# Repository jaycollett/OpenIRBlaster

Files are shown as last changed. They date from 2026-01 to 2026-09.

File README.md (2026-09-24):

# OpenIRBlaster

An open-source IR receiver and transmitter for Home Assistant. Custom PCB, 3D-printed case, ESPHome firmware, about $22 to $25 in parts.

[][releases]
[](LICENSE)
[][hacs]

📖 **[Read the full story and build guide on my blog](https://www.jaycollett.com/2026/02/openirblaster-finally-truly-simple-ir-control-for-home-assistant/)**

## The integration is deprecated. The hardware is not.

Home Assistant 2026.4 added a built-in `infrared` entity platform, and [HAIR](https://github.com/DAB-LABS/HAIR) builds a full IR code manager on top of it: a live signal sniffer, protocol decoding, climate state matrices, and import from SmartIR, Flipper Zero, LIRC and Girr. It does everything this integration does and a great deal more, and it is in the HACS default store.

So this integration is winding down. It still works, it is not going to break tomorrow, and nothing is being deleted in this release. It will not gain new features.

The hardware is unaffected and is where this project continues. OpenIRBlaster is a board, a case, a bill of materials and a firmware image, none of which HAIR provides.

**If you are already using this integration:** move your codes across before you delete its storage file. From version 1.3.2, removing the integration leaves that file in place. Version 1.3.1 and earlier deleted it along with the integration, so on those versions update or move your codes first. Your stored codes hold the carrier frequency measured when each was learned, and the new infrared platform does not report one, so anything re-learned later comes back at the 38 kHz default. See [Moving your codes to HAIR](#moving-your-codes-to-hair). Nothing is deleted and your setup keeps working while you check the result.

**If you are new here:** build the hardware, flash it, and use it with HAIR.

## What it is

A dedicated ESP8266 board built around IR, rather than a general-purpose dev board with an LED soldered on.

Transistor-driven IR LEDs (eight of them, 39 ohm limiting resistors, IRLML6344 MOSFET) give strong output and 360 degree coverage, so it works across a room rather than only when pointed at the target. A TSOP38238 receiver handles learning. The ESPHome firmware ships with `dashboard_import`, so the ESPHome dashboard can adopt the device with one click.

Everything needed to build one is in [`hardware/`](hardware/): schematic and board layout, the bill of materials, STLs for the case, the firmware source and a prebuilt binary.

## Requirements

- Home Assistant 2024.12 or newer for this integration.
- For HAIR, check its own requirements. Native IR capture and plucking need Home Assistant 2026.6 or newer, because that is the release where the infrared receiver API landed. 2026.9 or newer is the safer floor.
- An OpenIRBlaster board, or other ESPHome hardware with an IR receiver and transmitter.

See the [Hardware Overview](docs/hardware-overview.md) for the build.

## Moving your codes to HAIR

### Do this before you delete anything

Every code you learned here carries the carrier frequency measured when it was captured. Home Assistant's infrared platform does not report a carrier, so a code you learn again afterwards comes back at the 38 kHz default.

Most remotes are 38 kHz and would not notice. A device running at 36 or 40 kHz would, and for those the difference is the code working or not working. That measured value exists in one place only, this integration's storage file, and re-learning cannot bring it back.

Both routes below preserve it. Take one of them before you delete `.storage/openirblaster_<entry_id>`.

From version 1.3.2, removing the integration in Home Assistant keeps that file, so your codes are still on disk afterwards and the command-line export below can convert them. Version 1.3.1 and earlier deleted the file when you deleted the integration entry, so if you are on one of those versions, update or export first.

If you remove a blaster and add it again, Home Assistant gives it a new entry ID and a new, empty storage file. The old file stays next to it with your codes in it. Once those codes are safely in HAIR you can delete the old file by hand.

### Pluck from HAIR (recommended)

HAIR pulls the codes out of this integration directly. No files to move, no remote to point at anything, and no infrared is broadcast while it happens.

1. Install HAIR from HACS and set it up.
2. Open HAIR, go to the **Plucker** tab, and add OpenIRBlaster as a blaster.
3. Pluck your codes by name.

This works because the integration implements HAIR's pluckable contract. See [Plucking codes into HAIR](docs/pluckable.md) for what that means and how it works.

### Export to a file

If you would rather move files yourself, or HAIR is not installed yet.

From the UI, while this integration is still installed:

1. Go to **Developer Tools** -> **Actions**.
2. Choose **OpenIRBlaster: Export codes to HAIR**.
3. Pick your device, and optionally choose how to split the codes into files.
4. Run it.

Files land in `hair/wigs/` in your Home Assistant config directory, which is where HAIR looks.

HAIR treats one file as one remote, so the **Split into** option matters if your library covers several devices. Splitting by tag or by the first word of each code name gives you one remote per device instead of one long list. You can re-split inside HAIR later either way.

From the command line, which also works after you have removed the integration (on 1.3.2 or later, where removal keeps the file):

```bash
python3 tools/openirblaster_to_wig.py ~/.homeassistant/.storage/openirblaster_<entry_id>
```

The file name has no extension, and there is one per blaster, so `ls ~/.homeassistant/.storage/openirblaster_*` shows you what to pass.

Run `--help` for output directory and grouping options. It needs nothing but Python 3.12 or newer and never writes to the file it reads. `custom_components/openirblaster/wig_export.py` is the whole implementation in one file with no imports from anything else, so you can copy that single file somewhere and run it if the repository is not handy.

### After moving

Check the codes work in HAIR before removing anything here. If a code did not convert, or carried tags or notes, the file export writes `openirblaster-export-receipt.txt` next to the wigs listing what was dropped and why. Tags and notes have no equivalent in HAIR's format, so they are reported rather than silently merged.

Keep your `.storage` file until you are satisfied. Removing the integration does not touch it, so when you no longer need it, delete it by hand.

## Installation

### HACS

1. Open HACS.
2. Click **Integrations**.
3. Click **+ Explore & Download Repositories**.
4. Search for "OpenIRBlaster".
5. Click **Download**.
6. Restart Home Assistant.
7. Go to **Settings** → **Devices & Services** → **Add Integration** and search for "OpenIRBlaster".

### Manual

1. Download the [latest release](https://github.com/jaycollett/OpenIRBlaster/releases).
2. Copy `custom_components/openirblaster` into your Home Assistant `custom_components` directory.
3. Restart Home Assistant.
4. Add the integration from **Settings** → **Devices & Services**.

## Using the integration

### Learn a code

1. Find the **Code Name** text field in your device's entity list.
2. Enter a name, for example "TV Power".
3. Press **Learn IR Code**.
4. Within 30 seconds, point your remote at the receiver and press the button.
5. A new button entity appears with that name.

### Manage codes

Rename by calling `openirblaster.rename_code` with the code's `id` and a `new_name`. The button updates immediately and its entity ID does not change, so automations keep working.

Delete from **Settings** → **Devices & Services** → **OpenIRBlaster** → **Configure** → **Manage IR Codes**. Deletion is always select-then-confirm.

Codes can also be saved, sent, renamed and deleted from scripts. See the [Home Assistant Integration](docs/home-assistant-integration.md) docs for the full service reference.

### Use in automations

```yaml
automation:
  - alias: "Turn off TV at bedtime"
    trigger:
      - platform: time
        at: "23:00:00"
    action:
      - service: button.press
        target:
          entity_id: button.openirblaster_tv_power
```

## Compatibility

The integration finds devices by ESPHome project name, looking for firmware that declares `project.name: "jaycollett.openirblaster"`. If you are building your own hardware, include that identifier in your ESPHome YAML or fork the integration.

### Third-party devices

Community members have run OpenIRBlaster on hardware it was not designed for. See [`docs/third-party-devices/`](docs/third-party-devices/):

- [Tuya IR Blasters](docs/third-party-devices/tuya-ir-blasters.md), covering S06, S18 and similar Tuya-branded repeaters

[PRs adding a guide are welcome](docs/third-party-devices/README.md#contributing-a-new-device-guide).

## Documentation

Full documentation lives in [`docs/`](docs/README.md):

- [Hardware Overview](docs/hardware-overview.md), schematic, components and build guide
- [Firmware & ESPHome](docs/firmware-and-esphome.md), flashing and configuration
- [Home Assistant Integration](docs/home-assistant-integration.md), setup, entities, services and automation examples
- [Plucking codes into HAIR](docs/pluckable.md), how HAIR pulls codes out of this integration
- [Storage Format & Manual Editing](docs/storage-format.md), on-disk schema and hand-edit procedure
- [Troubleshooting](docs/troubleshooting.md), common issues and solutions

## Development

- [`TESTING.md`](TESTING.md), testing instructions
- [`hardware/`](hardware/), hardware design files

### ESPHome firmware

The firmware configuration is at [`hardware/firmware/factory_flash.yaml`](hardware/firmware/factory_flash.yaml). To contribute changes, modify the YAML, test on your own device, and keep event names, service calls and entity IDs compatible with the integration. See the [Firmware & ESPHome](docs/firmware-and-esphome.md) docs.

### Integration

```bash
git clone https://github.com/jaycollett/OpenIRBlaster.git
cd OpenIRBlaster
python3 -m venv venv
source venv/bin/activate
pip install -r requirements_dev.txt

pytest
```

## Support

- [Report bugs or request features](https://github.com/jaycollett/OpenIRBlaster/issues)
- [Project documentation](docs/README.md)

## License

MIT. See [LICENSE](LICENSE).

## Acknowledgments

Built for the Home Assistant community. Thanks to the ESPHome project for the firmware platform, to the Home Assistant community, and to [DAB-LABS](https://github.com/DAB-LABS/HAIR) for building the IR code manager this project no longer needs to.

### Transparency note: AI-assisted development

The Home Assistant integration for this project was developed with assistance from [Claude Code](https://claude.ai/code), Anthropic's AI coding assistant. AI-assisted development is a powerful tool when used responsibly by engineers who understand the code being generated, validate its correctness, and take ownership of the final result. I reviewed, tested, and take full responsibility for all code in this repository. AI assistance accelerated development but doesn't replace engineering judgment, thorough testing, or understanding of the underlying systems.

---

[releases-shield]: https://img.shields.io/github/v/release/jaycollett/OpenIRBlaster
[releases]: https://github.com/jaycollett/OpenIRBlaster/releases
[license-shield]: https://img.shields.io/github/license/jaycollett/OpenIRBlaster.svg
[hacs]: https://github.com/hacs/integration
[hacsbadge]: https://img.shields.io/badge/HACS-Default-orange.svg

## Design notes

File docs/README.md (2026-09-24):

# OpenIRBlaster Documentation

OpenIRBlaster is an open-source infrared transceiver designed for Home Assistant integration via ESPHome. These pages cover building, configuring, and troubleshooting the device.

For the project's elevator pitch and install instructions, see the [root README](../README.md). For a narrative build log, see the [project blog post](https://www.jaycollett.com/2026/02/openirblaster-finally-truly-simple-ir-control-for-home-assistant/).

## Hardware Specs

| Parameter | Value |
|---|---|
| Microcontroller | ESP-12F (ESP8266) |
| IR Frequency | 38kHz (configurable) |
| IR LEDs | 8x IR333-A 940nm |
| Power Input | 5V DC via USB-C |
| Power Draw | ~500mA peak (1A supply recommended) |
| Connectivity | Wi-Fi 802.11 b/g/n |

## Pages

### Getting Started
- [Hardware Overview](hardware-overview.md) - Schematic walkthrough, component selection, and design rationale

### Configuration
- [Firmware & ESPHome](firmware-and-esphome.md) - Flashing instructions, YAML configuration, and integration compatibility requirements
- [Home Assistant Integration](home-assistant-integration.md) - Device setup, entities, services, and automation examples

### Reference
- [Storage Format & Manual Editing](storage-format.md) - On-disk schema for `.storage/openirblaster_*` and the safe procedure for hand-editing it
- [Troubleshooting](troubleshooting.md) - Common issues and solutions

### Third-Party Hardware
- [Tuya IR Blasters](third-party-devices/tuya-ir-blasters.md) - S06, S18, and similar Tuya-branded IR repeaters
- [Adding a new device guide](third-party-devices/README.md#contributing-a-new-device-guide)

## Project Resources

| Resource | Link |
|---|---|
| Source Code | [GitHub Repository](https://github.com/jaycollett/OpenIRBlaster) |
| Hardware Files | [Eagle CAD Files](https://github.com/jaycollett/OpenIRBlaster/tree/master/hardware) |
| Blog Post | [Project Introduction](https://www.jaycollett.com/2026/02/openirblaster-finally-truly-simple-ir-control-for-home-assistant/) |
| ESPHome | [ESPHome Documentation](https://esphome.io) |

## Contributing

Contributions are welcome. Please submit issues and pull requests through the [GitHub repository](https://github.com/jaycollett/OpenIRBlaster).

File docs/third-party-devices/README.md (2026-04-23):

# Third-Party Device Support

OpenIRBlaster was designed around a [purpose-built PCB](../../hardware/), but the firmware and Home Assistant integration are not strictly tied to that hardware. Any ESPHome-flashable IR device that exposes the same events and services can work with the integration.

This directory collects community-contributed guides for running OpenIRBlaster on hardware that wasn't designed for it. These are provided as-is by the contributors listed in each guide; they may not have been tested by the maintainer.

## Available Guides

| Device Family | Notes | Contributor |
|---|---|---|
| [Tuya IR Blasters](tuya-ir-blasters.md) | Various Tuya-branded IR repeaters (S06, S18, etc.) flashed via tuya-cloudcutter | [@Stoatwblr](https://github.com/Stoatwblr) |

## What You'll Need to Make It Work

The Home Assistant integration identifies compatible devices by ESPHome project name. Any ESPHome YAML used with this integration must declare:

```yaml
esphome:
  project:
    name: "jaycollett.openirblaster"
    version: "1.0.0"
```

It also needs to expose the events and services the integration listens for. Use [`hardware/firmware/factory_flash.yaml`](../../hardware/firmware/factory_flash.yaml) as the reference implementation - the event names, service signatures, and entity IDs there define the contract.

## Contributing a New Device Guide

If you've successfully run OpenIRBlaster on hardware not listed here, PRs are welcome. A useful guide includes:

- Device name(s) and where to buy them
- The chip / board variant(s) you tested on
- Pinout(s) for IR TX, IR RX, status LED, and any buttons
- The flashing method (tuya-cloudcutter, esptool, etc.)
- A working ESPHome YAML snippet (or full file) showing the device-specific bits
- Anything that surprised you (case opening difficulty, GPIO probing, etc.)

Open a PR adding a new file to this directory and a row to the table above.

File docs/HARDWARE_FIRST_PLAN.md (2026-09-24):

# OpenIRBlaster hardware-first plan

Status: proposal, awaiting approval. No source files changed.
Written 2026-09-19 against v1.2.3 (commit 6e8f4ad, branch master, clean).

The premise: HAIR (https://github.com/DAB-LABS/HAIR, MIT) already did the infrared-domain migration this project was about to start, at a scope OpenIRBlaster was never going to match. HAIR owns no hardware and no firmware. OpenIRBlaster does. This plan moves the repo's centre of gravity to the hardware, makes OpenIRBlaster a first-class device under HAIR, and gets existing users' code libraries across without re-learning anything.

Sources. Repo claims carry a path or `file:line`. HAIR claims were read from the clone at `scratchpad/HAIR` and are cited `HAIR:<path>:<line>`; they agree with the independent analysis at `scratchpad/hair-analysis.md`, and where I measured something that document states more strongly than I can, I say so. ESPHome claims were read from `raw.githubusercontent.com/esphome/esphome/dev`. `infrared_protocols` claims were executed against version 10.1.0 under Python 3.14.7.

---

## Priority zero: the chip, and what each answer costs

### The hardware is ESP8266, ESP-12F module, ESPHome board `esp12e`

Settled from the repo, four independent confirmations:

- `hardware/BOM.csv:12`: `MCU,ESP8266,MCU,ESP-12F,ESP-12F`
- `hardware/firmware/factory_flash.yaml:21-22`: `esp8266:` then `board: esp12e`
- `hardware/firmware/factory_flash.yaml:195`: "Hardware schematic shows GPIO4/GPIO5 are swapped in the ESP-12F footprint"
- `custom_components/openirblaster/__init__.py:394`: `model="ESP8266 IR Blaster"`

There is no ESP32 variant anywhere in the repo. Every shipped unit is this board.

### Can ir_rf_proxy run on it

I cannot settle this from the repo and ESPHome source alone, and I will not guess. Here is exactly what the evidence does and does not establish.

Verified, and it is the encouraging half. Nothing gates ESP8266 at config time. I grepped `esphome/components/ir_rf_proxy/infrared.py`, `esphome/components/ir_rf_proxy/__init__.py` and `esphome/components/infrared/__init__.py` for `esp8266`, `esp32`, `only_on`, `not_on` and `PLATFORM`, and the only hit is `IS_PLATFORM_COMPONENT = True` (`infrared/__init__.py:22`). The C++ carries feature guards, `#ifdef USE_IR_RF` and `#ifdef USE_RADIO_FREQUENCY` (`ir_rf_proxy/ir_rf_proxy.h:9,13,19,45`), and no platform guards. The component is a thin layer over `remote_base` (`AUTO_LOAD = ["remote_base"]`, `infrared/__init__.py:20`), attaching by id through `remote_base.attach_receiver` (`ir_rf_proxy/infrared.py:89-90`). `remote_base` works on ESP8266 today, which is how the current firmware functions at all. So there is no structural reason it should fail.

Not verified, and it cannot be from source. Whether it compiles for `esp12e`, whether the image fits in flash, and whether it runs without exhausting RAM once the native API also holds an infrared receive subscription. The existing firmware is already managing RAM deliberately: `buffer_size: 6kb` and a comment at `factory_flash.yaml:204` reading "ESP8266-safe: avoid dump: all (can contribute to RAM pressure)". That is not a board with headroom.

The discouraging half, and it deserves weight. Nobody upstream has an ESP8266 config.

- All five HAIR reference configs are ESP32 family: `esp32dev`, `esp32-c3-devkitm-1`, `esp32doit-devkit-v1`, `esp32-s3-devkitc-1`, `seeed_xiao_esp32c3` (`HAIR:esphome/README.md`, availability table).
- The official `esphome/infrared-proxies` repo contains exactly one device directory, `xiao-ir-mate`, ESP32-C3. I listed the repo through the GitHub API.
- ESPHome's own `ir_rf_proxy` docs publish no chip support matrix, which the parallel analysis also found (`hair-analysis.md:94`).

Zero ESP8266 prior art across all three. That is not proof of failure. It does mean OpenIRBlaster would be first, with nobody to copy and nobody to ask.

### What would settle it

One command, which the parallel agent is running:

```
esphome compile factory_flash.yaml    # with the infrared: block from section 2, ESPHome 2026.5.0+
```

Three outcomes worth distinguishing, because they are not the same problem:

1. Compiles and fits, runs stable. Proceed with the whole plan.
2. Compiles but overruns flash or RAM. Recoverable by trimming the firmware: drop `dump:`, drop the legacy `send_ir_raw` and `replay_last_ir` services and the `openirblaster_learned` event once HAIR is the path, shrink `buffer_size`. That reclaims real space, since those exist only to serve the integration this plan winds down.
3. Does not compile for `esp8266`. Not recoverable in firmware.

### Consequences of each answer

If it works, existing units follow with a reflash and no board revision. Everything below proceeds as written.

If it does not, there is no fallback. HAIR talks only to the infrared domain ("HAIR does not talk to hardware directly. It sits on HA's native infrared platform for both capture and send", and `dependencies: ["http", "infrared"]` in `HAIR:custom_components/hair/manifest.json`). A device that cannot register an `infrared` entity is invisible to HAIR, whatever else its firmware exposes. The legacy event and service path does not help, because HAIR will not read it.

That leaves two branches, and both are Jay's call rather than mine:

- Revise the board to ESP32-C3. A schematic change, a new BOM, a new layout, a fab run and new firmware. Weeks and real money. It also gets the chip everyone else in this ecosystem is on, which has value beyond this one problem.
- Accept that Rev A stays on the legacy integration and only a future revision works with HAIR. Cheap now, and it means the wind-down in section 4 cannot go past a thin shim, because the shim is the only way Rev A users keep working at all.

Note what does not change under either branch. The export tool in section 3 reads a JSON file and writes a JSON file. It never touches the device. Existing users get their code libraries out regardless of how the compile goes, and that is why it is the first thing to build.

---

## 1. Hardware asset inventory

Eight files, 1.2 MB, all under `hardware/`.

| Asset | Path | Size | Notes |
|---|---|---|---|
| Schematic | `hardware/Eagle Files/Open_IR_Blaster.sch` | 607 KB | Autodesk Eagle format |
| Board layout | `hardware/Eagle Files/Open_IR_Blaster.brd` | 111 KB | Autodesk Eagle format |
| Schematic image | `hardware/Eagle Files/open_ir_blaster_sch.png` | 100 KB | Rendered, viewable without Eagle |
| Bill of materials | `hardware/BOM.csv` | 693 B | 14 line items |
| Enclosure top | `hardware/3DPrinterFiles/Top.stl` | 206 KB | STL only |
| Enclosure bottom | `hardware/3DPrinterFiles/Bottom.stl` | 347 KB | STL only |
| Factory firmware source | `hardware/firmware/factory_flash.yaml` | 9.3 KB | ESPHome YAML, project version `0.5.0` at line 14 |
| Factory firmware binary | `hardware/firmware/factory_flash.bin` | 420 KB | Prebuilt, flashable via ESPHome Web |

### What does not exist

Checked rather than assumed, because the brief asked for several of these by name:

- No gerbers. I searched the repo for `*.gbr`, `*.gbl`, `*.gtl`, `*.drl` and `*.zip` and found none. The Eagle `.brd` can generate them, but no fab-ready output is committed, so nobody can order a board from this repo without installing Eagle and running a CAM job.
- No drill files, pick-and-place, fab notes or assembly drawing.
- No KiCad project. Eagle only, which matters because Eagle is end-of-life as a standalone product and KiCad is where the open-hardware audience now is.
- No STEP, 3MF or source CAD for the case. Two STLs, so it cannot be modified without remodelling it.
- No hardware-scoped licence. The repo `LICENSE` covers the software; board and case normally carry a separate CERN-OHL or CC-BY-SA.

For a repo whose argument is about to become "we own the hardware", the missing fab package is the most visible gap.

### Circuit summary

| Function | Part | GPIO | Config |
|---|---|---|---|
| IR receive | TSOP38238, 38 kHz (`BOM.csv:14`) | GPIO5 | `INPUT_PULLUP`, inverted (`factory_flash.yaml:197-202`) |
| IR transmit | IR333-A 940 nm (`BOM.csv:13`) via IRLML6344 MOSFET (`BOM.csv:10`) | GPIO14 | `carrier_duty_percent: 50%` (`factory_flash.yaml:283-285`) |
| LED current limiting | 8 x 39 ohm R1210 (`BOM.csv:6`) | | Eight in parallel, a hard-driven emitter |
| Power | Adafruit 4907 USB port (`BOM.csv:8`), AZ1117IH-3.3 (`BOM.csv:9`) | | |

Receiver tuning today: `buffer_size: 6kb`, `tolerance: 50%`, `filter: 50us`, `idle: 25ms`, `dump: raw` (`factory_flash.yaml:204-213`).

The firmware ships `dashboard_import` (`factory_flash.yaml:17-19`) pointing at `github://jaycollett/OpenIRBlaster/hardware/firmware/factory_flash.yaml@master`, so the device is adoptable straight from the ESPHome dashboard. That is a real distribution asset and it should survive every change below.

---

## 2. ESPHome ir_rf_proxy configuration

Conditional on priority zero. Do not ship this until the compile passes.

### 2.1 How the component works, and why the legacy path survives

`ir_rf_proxy` is a platform of ESPHome's `infrared:` component. Its schema requires exactly one of `remote_transmitter_id` or `remote_receiver_id`, each a `cv.use_id` reference to an existing component (`ir_rf_proxy/infrared.py:24-38`). It sits on top of `remote_receiver` and `remote_transmitter` rather than replacing them, so a device doing both needs two entries against the same hardware.

That is what makes the transition cheap and reversible. Adding an `infrared:` block is purely additive. The existing `send_ir_raw` service (`factory_flash.yaml:30-43`), the `esphome.openirblaster_learned` event (`:64-77`, `:261-266`) and the `replay_last_ir` recovery service keep working against the same `ir_rx` and `ir_tx` ids. One firmware serves both the legacy integration and HAIR, so users migrate on their own schedule instead of on a flag day, and a bad ESPHome release does not strand anybody. Keep both blocks.

Two config rules, read from source:

- A transmitter whose `carrier_duty_percent` is 0 or 100 is rejected at final validation (`ir_rf_proxy/infrared.py:63-69`). OpenIRBlaster already sets 50% (`factory_flash.yaml:285`), so this passes unchanged.
- `receiver_frequency` is rejected on a transmitter entry (`ir_rf_proxy/infrared.py:44-48`), and on a receiver entry the source calls it "metadata only, no hardware effect" (`:92-94`). It never reaches Home Assistant, which is why captured signals arrive with `modulation=None`.

Require ESPHome 2026.5.0 or newer, not the bare 2026.1.0 minimum. The component broke HA entity setup as late as 2026-02-24, gained `receiver_frequency` in March and an `on_control` trigger in May. It is also marked EXPERIMENTAL in its own source, verbatim: "This component is EXPERIMENTAL. The API (both Python configuration and C++ interfaces) may change at any time without following the normal breaking changes policy." (`infrared/__init__.py:4-8`).

### 2.2 Proposed config

Written to HAIR's contribution convention. Their header template (`HAIR:esphome/_template/header-template.yaml`) is mandatory, and their README states PRs without a fully filled header are not merged.

```yaml
# ============================================================================
# HAIR ESPHome Config
# ----------------------------------------------------------------------------
# Device:            OpenIRBlaster (ESP-12F / ESP8266)
# Hardware revision: Rev A
# Variant:           full
# Contributor:       @jaycollett
# Source:            https://github.com/jaycollett/OpenIRBlaster
# License:           Apache 2.0
# Tested against:
#   HAIR:            <fill after testing>
#   HA Core:         <fill after testing>
#   ESPHome:         <fill after testing, 2026.5.0 minimum>
# Last verified:     <YYYY-MM-DD>
# Purpose:           RX+TX
# Hardware purchase: DIY, see hardware/ in the repo
# GPIO map:
#   GPIO5            IR RX (TSOP38238, inverted, pull-up)
#   GPIO14           IR TX (IR333-A via IRLML6344)
# Notes:
#   - ESP8266. No ESP8266 ir_rf_proxy reference config exists upstream.
#     Compile-tested on esp12e, see the repo for results.
#   - dump: is omitted deliberately. The proxy attaches to remote_receiver
#     directly and does not need it; on ESP8266 the decoders cost RAM.
#   - The legacy send_ir_raw service and openirblaster_learned event are
#     retained so the pre-HAIR path still works on the same firmware.
# ============================================================================

infrared:
  - platform: ir_rf_proxy
    name: "${friendly_name} TX"
    id: ir_proxy_tx
    remote_transmitter_id: ir_tx

  - platform: ir_rf_proxy
    name: "${friendly_name} RX"
    id: ir_proxy_rx
    receiver_frequency: 38kHz
    remote_receiver_id: ir_rx
```

Three changes to `remote_receiver` (`factory_flash.yaml:197-213`) worth making at the same time:

Drop `dump: raw`. It only drives log output. The proxy gets timings through `remote_base.attach_receiver` regardless, so removing it costs nothing and buys RAM on the chip that section 0 says has none to spare. If outcome 2 from priority zero happens, this is the first thing to cut anyway.

Raise `idle` from 25 ms. HAIR's references use 100 ms (`HAIR:esphome/generic-esp32-c3/generic-esp32-c3-minimal.yaml:87`). At 25 ms a long air-conditioner frame can be truncated mid-signal, which presents as a code that captures but does not replay. Climate matrices are something HAIR is good at, so this matters more under HAIR than it did before.

Consider `tolerance` 25% instead of 50%. HAIR uses 25%; 50% is loose enough to merge symbols on some protocols. Change this only if capture testing says so, since the current value is recorded in the repo as a stable result from prior testing.

---

## 3. Code library export tool

The priority deliverable for existing users. Nothing else here matters to them if the codes they learned one press at a time do not survive.

### 3.1 Answering the carrier_hz question first

The brief asked whether `.wig.json` can hold `carrier_hz` and what is lost if not. Good news: it holds it, and nothing is lost.

A wig has no `carrier_hz` field, no `pulses` field and no `timings` field. The payload is Pronto hex only (`HAIR:custom_components/hair/wig_format.py:1-14`). That looks like a problem until you look at what Pronto is. The second word of a Pronto preamble is the carrier, encoded as a divisor of a fixed reference frequency (`infrared_protocols/commands/pronto.py:13`, `:59-78`). Encoding `{pulses, carrier_hz}` into Pronto writes the carrier into the code, and any reader gets it back.

I measured the round trip rather than taking it on faith:

| carrier_hz in | preamble word | decoded back | error |
|---|---|---|---|
| 36000 | `0073` | 36045 Hz | +45 Hz (0.13%) |
| 38000 | `006d` | 38029 Hz | +29 Hz (0.08%) |
| 40000 | `0068` | 39857 Hz | -143 Hz (0.36%) |
| 56000 | `004a` | 56015 Hz | +15 Hz (0.03%) |

The analysis document says Pronto "preserves the carrier exactly" (`hair-analysis.md:366`). It preserves it to the quantization of the frequency word, which is within 0.36% across the whole IR band. A TSOP receiver has a passband thousands of Hz wide, so this is irrelevant in practice, and calling it exact is close enough for a user-facing sentence. It is not literally exact, so a converter should not assert byte-equality in a test.

The wider point is worth stating plainly, because it inverts the concern behind the question. Jay's existing codes carry real captured carrier values. New captures through `ir_rf_proxy` will not, because ESPHome delivers `modulation=None`. Exporting to `.wig.json` now, from the current library, is the one moment where those measured carriers are still in hand. Every code exported keeps its 36 kHz or 40 kHz forever. Every code re-learned through the new path after deleting the old library comes back at the 38 kHz default. That is an argument for doing the export before anything else, and for telling users not to delete their `.storage` file until they have run it.

### 3.2 Source schema, OpenIRBlaster

Storage lives at `<HA config>/.storage/openirblaster_<entry_id>`, one file per device, in Home Assistant's standard `Store` envelope with the payload under `data`. The envelope is built at `custom_components/openirblaster/storage.py:84-92`; the store is constructed at `storage.py:69-74` with `STORAGE_VERSION` and `STORAGE_MINOR_VERSION` from `const.py:35-36`, currently 1 and 1.

One code object, written at `storage.py:143-152`:

| Field | Type | Source | Meaning |
|---|---|---|---|
| `id` | string | `storage.py:144`, generated at `:211-227` | Lowercase slug from the original name, collision-suffixed `_2`, `_3`. Stable across renames |
| `name` | string | `storage.py:145` | Display name, mutable |
| `carrier_hz` | int | `storage.py:146` | Validated `> 0` at `learning.py:644-650`, typically 38000 |
| `pulses` | list[int] | `storage.py:147` | Signed microseconds, positive mark and negative space. Max 2000 (`const.py:22`) |
| `created_at` | ISO string | `storage.py:148` | UTC |
| `updated_at` | ISO string | `storage.py:149` | UTC |
| `tags` | list[string] | `storage.py:150` | May be empty |
| `notes` | string | `storage.py:151` | May be empty |

The device block also carries `config_entry_id`, `name`, `device_id` and an optional `last_learned` summary (`storage.py:259-263`). The whole format is already documented for users at `docs/storage-format.md`.

The sign and unit convention matches HAIR's encoder input contract exactly, which is why this conversion is arithmetic rather than interpretation.

### 3.3 Target schema, `.wig.json`

From `hair-analysis.md` section 8, cross-checked against the clone. A wig is one JSON object describing one remote. A minimal valid file:

```json
{
    "format": "hair-wig/3",
    "name": "Living Room TV",
    "signals": [
        {"alias": "Power", "pronto": "0000 006d 0004 0000 0156 00ac 0015 0017"}
    ]
}
```

Required on parse (`wig_format.py:537-711`): `format` matching `^hair-wig/(\d+)$`, a non-empty `name`, and a non-empty `signals` list whose entries each have a non-empty `alias` and a `pronto` that passes `validate_pronto`. Stamp `hair-wig/3`, which is what the current exporter writes for a flat wig (`wig_format.py:1037-1039`). Known per-signal keys are `alias`, `pronto`, `send_count`, `send_spacing_ms`, `ditto_count`, `bypass_protocol` (`wig_format.py:318-321`). For a converter, only `alias` and `pronto` matter; leave the rest out and let the parser apply defaults.

Unknown keys are tolerated and preserved through parse and re-serialize, at top level and per signal, which is the documented growth mechanism. A converter can safely stamp private keys.

Two schema slots worth using. `converted_from` and `converted_from_sha256` (`wig_format.py:120-121`) are the provenance pair: name the source tool and hash the `.storage` file it came from. `kind` comes from a fixed 27-word vocabulary (`wig_format.py:172-200`) and HAIR's own exporter refuses to guess one; the converter should leave it unset and let HAIR ask. File cap is 16 MB (`wig_format.py:102`), suffix `.wig.json`.

Import needs no HAIR code at all. Drop the file into `/config/hair/wigs/` over SSH or Samba and HAIR picks it up, which means the converter never has to integrate with anything.

### 3.4 The conversion

Use `ProntoCommand` from `infrared_protocols`, which ships with Home Assistant as a requirement of the `infrared` domain:

```python
from infrared_protocols.commands.pronto import ProntoCommand

pronto = ProntoCommand.from_raw_timings(code["pulses"], modulation=code["carrier_hz"]).to_pronto_hex()
# -> "0000 006d 0004 0000 0156 00ac 0015 0017 0015 0041 0015 05cb"
```

HAIR's own `raw_to_pronto(timings, frequency=...)` (`HAIR:custom_components/hair/ir_command.py:357`) does the same job and is 50 lines of dependency-free arithmetic that could be vendored. Prefer the `infrared_protocols` route for a standalone script, since it is already installed next to Home Assistant.

Four facts I verified by execution rather than reading:

Output case is lowercase and that is fine. `to_pronto_hex` builds from `bytes.hex()` (`pronto.py:81-83`), so words come out `006d` not `006D`. HAIR's validator accepts both (`pronto_validator.py:67`) and its canonical form lowercases anyway (`wig_format.py:1410-1420`).

The header is always `0000`, the modulated learned format, which is one of the two headers HAIR accepts (`0000` and `0100`). Compatible without special handling.

Odd-length pulse arrays fail. Pronto encodes burst pairs, so an array ending on a mark with no trailing space raises `ValueError: pronto timing data does not match the preamble burst pair counts`. I reproduced it with a 7-element array. Whether OpenIRBlaster ever writes odd-length arrays depends on how the firmware's `on_raw` handler terminates, which I did not trace. The converter should append a trailing gap when the length is odd and record it in the receipt rather than doing it silently.

Timings quantize, by up to 45µs on a 560µs interval, about 8 percent. Well inside NEC-family decode tolerance, which is 40 percent in the same library (`nec.py:15`). Worth spot-checking converted codes against real hardware before telling users the export is safe, particularly for long air-conditioner frames.

### 3.5 Field mapping

| OpenIRBlaster | wig | Handling |
|---|---|---|
| `data.device.name`, or the entry title | `name` | Required. Fall back to "OpenIRBlaster" plus the entry id |
| `code.name` | `signals[].alias` | Required, stripped, preserved verbatim |
| `code.pulses` + `code.carrier_hz` | `signals[].pronto` | Both encode into the one string. Carrier included |
| source file SHA-256 | `converted_from_sha256` | Provenance |
| (tool name) | `converted_from` | Provenance |
| `code.notes` | no per-signal target | Receipt file |
| `code.tags` | no target | Receipt file |
| `code.id` | no target | Dropped. Aliases are display names; HA entity ids are not portable |
| `code.created_at`, `code.updated_at` | no target | Dropped |
| (user choice) | `kind`, `brand`, `model` | Left unset. HAIR asks |

`notes` and `tags` are the only real loss, and it is small. They are per-code in OpenIRBlaster with no per-signal equivalent in a wig, which carries a single top-level `notes` string. Do not concatenate them into it; a merged blob attributed to no particular code is worse than nothing. Write a sidecar receipt listing code id, name, tags and notes, so anything worth keeping can be pasted back by hand. HAIR's own exporter does the same kind of skip accounting and surfaces it beside the export (`HAIR:custom_components/hair/wig_export.py:64-71`).

### 3.6 Grouping and delivery

One wig is one remote. An OpenIRBlaster library is a flat list per device, so a 40-code library covering three devices becomes one wig of 40 unrelated buttons unless the converter splits it. Offer `--group-by` with `file` (default, one wig per storage file, always correct if untidy), `tag` (one per distinct tag, remainder wig for untagged, best outcome for anyone who used tags) and `prefix` (split on the first name token, which suits the common "TV Power" / "TV Volume Up" habit). Users can re-split inside HAIR either way.

Ship it as `tools/openirblaster_to_wig.py` in this repo. No HAIR dependency, no HA import, reads a `.storage` file and writes wigs plus a receipt. Take a path in, write to a directory, never touch the source. Point the docs at the existing warning in `docs/storage-format.md` about HA caching `.storage` in memory.

Second, and not blocking: contribute a format probe and adapter to HAIR so users can drag the raw `.storage` JSON into its drop zone. HAIR dispatches on a prioritized probe list (`HAIR:custom_components/hair/wig_adapters.py:196-203`) already carrying SmartIR, Girr, Flipper and LIRC. An `openirblaster` probe is an easy match: a JSON object with `data.codes` whose entries have `id`, `pulses` and `carrier_hz`. That is the nicer experience and it puts OpenIRBlaster's name in HAIR's supported-formats list, which is free visibility for the hardware. It is also a PR on someone else's schedule, so the script must not wait for it.

---

## 4. Integration wind-down

Options with tradeoffs, not a decision. My recommendation is at the end.

### Option A: thin turnkey shim

Strip the integration to what HAIR does not cover. In practice: drop learning entirely, since HAIR's sniffer is better, and keep a read-only view of the existing library with its send buttons.

A v1.2.3 user upgrades, keeps their buttons, loses the Learn button, gains nothing. New codes go in HAIR, old codes stay in OpenIRBlaster storage, and the library is split permanently. Any HA change to the ESPHome event or service API is still Jay's to fix.

Nobody's dashboard breaks, which is the argument for it. Against: it preserves the exact thing this pivot exists to end, and guarantees every user ends up with two libraries.

This becomes the only viable option if priority zero fails, because a shim is then the only way Rev A hardware works at all.

### Option B: deprecate with a migration path

Ship a deprecation release that adds an `openirblaster.export_to_hair` service and an options-flow button writing the `.wig.json` from section 3 straight into `/config/hair/wigs/`, raises a persistent repair issue explaining the move and linking HAIR, and updates the README and HACS description. Everything else keeps working. After a stated grace period, stop feature work and archive.

A v1.2.3 user upgrades, nothing breaks, they get a notice and a one-click export. They install HAIR, import, and remove the old integration when ready. Nobody is forced and nobody re-learns a code.

Most work of the three, and most of that work is the export, which section 3 says to build regardless. The deprecation release is a thin wrapper over it.

### Option C: freeze

Stop releasing. README points at HAIR. Code stays on master and keeps working until HA breaks it.

A v1.2.3 user notices nothing until something breaks, then finds an unmaintained integration and no migration path. The dependency is on `esphome` event and service APIs, which are stable, so that could be a long time. Zero effort, worst experience, and it wastes the export by not putting it in front of anyone.

### Recommendation

Option B, shipped as **v1.2.4** rather than a 1.3. The version number is doing real work here: 1.3.0 signals a feature release and invites users to expect continued development, while a patch bump reads as what it is, a maintenance release whose entire content is the exit path. It also keeps the door open to a genuine 1.3.0 later if priority zero fails and option A becomes necessary.

Sequence it so the export ships before the deprecation notice, not with it. A repair issue telling users to migrate, pointing at a tool that does not exist yet, is worse than saying nothing.

### What the HACS entry should say

`hacs.json` currently reads `{"name": "OpenIRBlaster", "homeassistant": "2024.12.0"}`. Under option B the description should say in its first line that this is the integration for OpenIRBlaster hardware, that HAIR is the recommended way to use the device going forward, and that this integration exists to carry existing libraries across. It should not read as a competing general-purpose IR integration, because it stops being one.

One release mechanic, recorded in `docs/SESSION_KNOWLEDGE.md`: the Release workflow auto-tags and publishes from `manifest.json` on every master push, and CI fails any master push whose manifest version matches the latest release tag. Docs-only commits cannot be pushed alone; bundle them with a version bump.

### Version floors carried forward from the v2 research

These stop being OpenIRBlaster's problem under this plan, and become facts to state accurately in the docs, because they now describe what HAIR requires of a user rather than what Jay has to build against.

- The infrared receiver API landed in HA 2026.6.0, not 2026.4.0. I verified this by fetching `homeassistant/components/infrared/__init__.py` at every release tag: `async_subscribe_receiver` is absent at 2026.4.0 and 2026.5.0 and present from 2026.6.0. HAIR's `hacs.json` floors at 2026.4.0, which is correct for its emitter-only and bridge paths but not for native capture. Recommend 2026.9.0 in OpenIRBlaster's own docs.
- Python 3.14 is a hard floor for anything importing `infrared_protocols` (`requires-python = ">=3.14"`, verified from PyPI metadata). HA 2026.6+ requires it anyway. This repo's CI runs Python 3.12 (`docs/SESSION_KNOWLEDGE.md`), so the export tool's test job needs 3.14 even though the shipped integration does not.
- `infrared-protocols` went from 1.1.0 to 10.1.0 in five months, ten majors, with two breaks I verified in code: `get_raw_timings()` changed return type, and the code factory moved from a module-level `make_command` to an `Enum.to_command` method. Core owns the pin, so pinning is unavailable. The export tool uses only `ProntoCommand.from_raw_timings` and `to_pronto_hex`, which is the narrowest possible surface, and vendoring the 50 lines of Pronto arithmetic is the escape hatch if that surface moves.

---

## 5. README and positioning

The repo currently presents as a Home Assistant integration that happens to have hardware. Invert that.

Open by saying what the hardware is: an open-source ESP8266 IR blaster for Home Assistant, with schematic, board, BOM, enclosure and prebuilt firmware in the repo, linking the rendered schematic PNG so people can see it without Eagle. Then how to get one, which today means building it and should say so honestly until a fab package exists. Then how to flash it, where `dashboard_import` already gives a one-click path from the ESPHome dashboard.

Then the part that changes. Point at HAIR as the recommended software, link its repo and HACS entry, and link the OpenIRBlaster ESPHome config once contributed. Say plainly that the device registers as a standard Home Assistant infrared emitter and receiver, so it works with anything built on that platform. That one sentence is worth more than a feature list, because it says the hardware is not locked to a single piece of software, which is the whole argument for owning hardware instead of an integration.

Close with a short legacy section: what the integration was, that it still works, that it is deprecated in favour of HAIR, and where the export tool lives.

Two distribution moves beyond this repo. Contribute the config to HAIR, which preserves contributor attribution permanently in the header. Also submit to `esphome/infrared-proxies`, the Home Assistant team's own IR proxy config repo, which currently lists one device. Being the second entry there, and the only ESP8266 one, is real visibility for a small hardware project.

Two hygiene items that make the repo read as hardware rather than software with attachments: add a hardware licence distinct from the software `LICENSE`, and publish the fab package from item 3 below.

---

## 6. Ordered plan

Effort in developer-days. Item 0 gates items 2 and 4 and shapes item 5.

### 0. Compile and run ir_rf_proxy on esp12e, 0.5 day

Already running in parallel. Build `factory_flash.yaml` plus the section 2.2 block for `board: esp12e` against ESPHome 2026.5.0+. Confirm it compiles, fits, flashes, produces two `infrared` entities, captures and sends. Record the result in `docs/SESSION_KNOWLEDGE.md` either way, since it is the kind of finding that is expensive to rediscover.

### 1. Code library export tool, 2 days

`tools/openirblaster_to_wig.py` per section 3. Storage reader, Pronto encoding with the odd-length guard, three grouping modes, receipt file, tests against a real exported library on Python 3.14. Independent of item 0, so start it immediately and in parallel. It is what users need most and it works regardless of how the compile goes.

### 2. ESPHome config and firmware release, 1 day

Depends on item 0. Add the `infrared:` block, drop `dump:`, raise `idle`, decide `tolerance` from capture testing, fill the header's tested-against versions, bump `esphome.project.version` from `0.5.0` (`factory_flash.yaml:14`), rebuild `factory_flash.bin`, update `docs/firmware-and-esphome.md`. Keep the legacy service, event and replay path in place.

### 3. Fab package, 1 day

Generate gerbers and drill files from `Open_IR_Blaster.brd`, commit under `hardware/fab/` with a short README naming stackup and fab-house settings. Add a hardware licence. Consider exporting a KiCad project alongside the Eagle files. This is the single change that most turns the repo into something other people can build, and it is the one item here that nobody else in this ecosystem can do for Jay.

### 4. Contribute configs upstream, 0.5 day

Depends on items 0 and 2. PR to HAIR with a filled header, and to `esphome/infrared-proxies`. Small PRs into other people's repos, so open them early and expect them to land on someone else's schedule.

### 5. Deprecation release v1.2.4, 1.5 days

Option B. Wire the item 1 export into an `openirblaster.export_to_hair` service and an options-flow entry writing into `/config/hair/wigs/`, add the deprecation repair issue and strings, update `hacs.json`. Ship after item 1, never before. If item 0 failed, this becomes option A instead and the scope changes.

### 6. README and positioning, 1 day

Section 5. README, `docs/README.md`, the HACS description, and a `docs/SESSION_KNOWLEDGE.md` entry recording why the project pivoted and what the compile found.

### Totals

| Scope | Items | Days |
|---|---|---|
| Everything | 0 through 6 | 7.5 |
| If item 0 fails, no firmware path | 0, 1, 3, 5 as option A, 6 | 5.5 |
| Minimum that gets users their codes | 0, 1, 6 | 3.5 |

Item 1 is worth doing whatever item 0 returns, and it should start now rather than after. Item 3 is worth doing whatever happens to any of the software, because it is the part of this repo nobody else can replace.

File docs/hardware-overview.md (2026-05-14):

# Hardware Overview

This page covers the hardware components and assembly for the OpenIRBlaster.

## Recommended Components

| Component | Specification | Notes |
|---|---|---|
| Microcontroller | ESP8266 (ESP-12E/ESP-12F) or ESP32 | ESP-12F recommended |
| IR Receiver | TSOP38238 | Connected to GPIO5 |
| IR LED | 950nm IR LED (IR333-A or similar) | Connected to GPIO14 |
| MOSFET | IRLML6344 or similar logic-level | For driving IR LED(s) |
| Power | 5V DC via USB-C | 1A supply recommended |

## Circuit Design

The OpenIRBlaster uses a simple but effective design:

- **IR Receiver**: The TSOP38238 connects directly to GPIO5 with built-in signal conditioning
- **IR Transmitter**: GPIO14 drives an IRLML6344 MOSFET which switches the IR LED array
- **Power**: 5V USB-C input with AZ1117-3.3 voltage regulator for the ESP8266

### Schematic

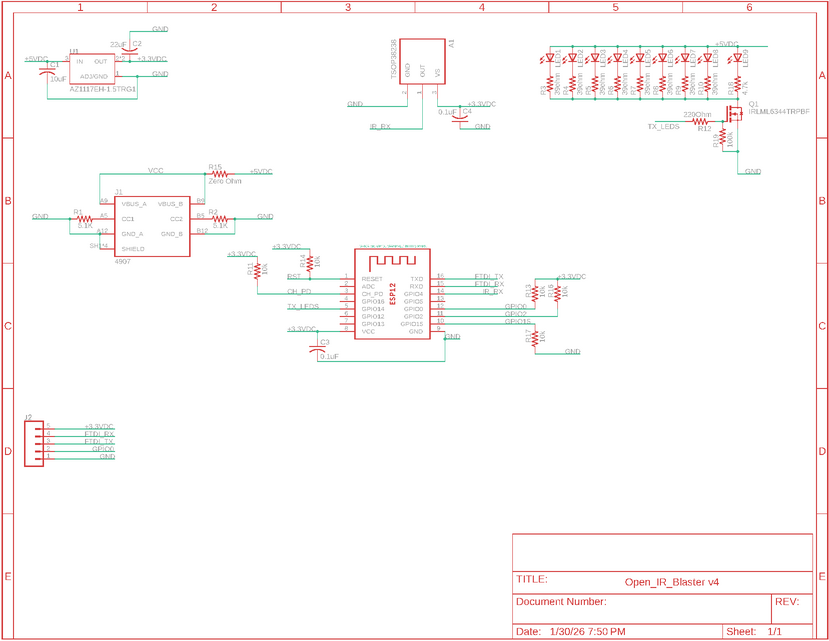
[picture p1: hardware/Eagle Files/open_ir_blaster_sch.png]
OpenIRBlaster Schematic


Full Eagle CAD files are available in the [hardware/Eagle Files](https://github.com/jaycollett/OpenIRBlaster/tree/master/hardware/Eagle%20Files) directory.

## GPIO Assignments

| GPIO | Function |
|---|---|
| GPIO5 | IR Receiver (TSOP38238) |
| GPIO14 | IR Transmitter (via MOSFET) |

## Build Options

### Option 1: Custom PCB

Order PCBs using the Eagle files in the repository. The board is designed for easy hand soldering with 0805 SMD components.

### Option 2: Breadboard Prototype

For testing, you can wire up the components on a breadboard:
1. Connect TSOP38238 to GPIO5
2. Connect IR LED through MOSFET to GPIO14
3. Add appropriate current limiting resistor for IR LED

For a full narrative build walkthrough, see the [project blog post](https://www.jaycollett.com/2026/02/openirblaster-finally-truly-simple-ir-control-for-home-assistant/).

## Design Files

- [Eagle Schematic (.sch)](https://github.com/jaycollett/OpenIRBlaster/tree/master/hardware/Eagle%20Files)
- [Eagle Board (.brd)](https://github.com/jaycollett/OpenIRBlaster/tree/master/hardware/Eagle%20Files)

---

*See [Troubleshooting](troubleshooting.md) for hardware debugging tips.*

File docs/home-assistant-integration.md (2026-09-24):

# Home Assistant Integration

This page covers setting up and using the OpenIRBlaster integration with Home Assistant (integration v1.2.x, HA 2024.12 or later).

## Installation

### HACS (Recommended)

1. Open HACS in your Home Assistant instance
2. Click on **Integrations**
3. Click the **+ Explore & Download Repositories** button
4. Search for "OpenIRBlaster"
5. Click **Download**
6. Restart Home Assistant

### Manual Installation

1. Download the [latest release](https://github.com/jaycollett/OpenIRBlaster/releases)
2. Extract and copy the `custom_components/openirblaster` folder to your Home Assistant `custom_components` directory
3. Restart Home Assistant

## Setup

1. Navigate to **Settings** → **Devices & Services**
2. Click **+ Add Integration**
3. Search for "OpenIRBlaster"
4. Select your ESPHome OpenIRBlaster device from the dropdown
5. Click **Submit**

If you later rename the device in ESPHome, you do not need to remove and re-add the integration - see [Reconfiguring After an ESPHome Rename](#reconfiguring-after-an-esphome-rename).

## Entities and Device Layout

Each blaster is a single device in Home Assistant. Its entities are grouped by section on the device page:

### Controls (main section)
- **{Your Code Names}** - one button per saved code; press to transmit
- **Code Activity** - an event entity that records every capture and save (see [Automating on Code Activity](#automating-on-the-code-activity-event))

### Configuration
- **Code Name** - text field: the name for the next code you learn
- **Learn IR Code** - button: arms learning mode
- **Send Last Learned** - button: replays the most recently captured code (handy for testing before you save)

### Diagnostic
- **Last Learned Code Name** - name of the most recently saved code
- **Last Learned Timestamp** - when the last code was captured
- **Last Learned Pulse Count** - size of the last code (for debugging)

> Upgrading from an older version? The separate "Controls" device is gone; its entities now live on the main device under Configuration. The migration happens automatically at startup.

## Adding a Code

### From the UI (recommended)

1. On the device page, type a name into the **Code Name** field (e.g., "TV Power")
2. Press **Learn IR Code**
3. Within 30 seconds, hold your remote 2-6 inches from the IR receiver and press the button you want to capture
4. A "Code Learned" notification appears, the new code button shows up immediately (no restart or reload needed), and the Code Name field clears itself

Notes on this flow:

- **Timeout:** if no signal arrives within 30 seconds, learning stops, the device's learning mode is switched off, and a "Learning Timed Out" notification appears. Just press **Learn IR Code** again to retry.
- **Duplicate names:** if the name already exists, a "Duplicate Name" notification appears and nothing is saved - pick a different name and learn again.
- **Empty name:** pressing **Learn IR Code** with an empty Code Name shows a "Name Required" notification and does not arm learning.
- **Garbled capture:** if the device receives something it cannot validate, a "Learning Cancelled" notification appears with the reason.

If the integration doesn't pick up the learned code even though ESPHome logs show the IR signal arrived, see [Troubleshooting](troubleshooting.md#ir-receiver-not-learning-codes). As a last resort, codes can be added manually to the storage file - see [Storage Format & Manual Editing](storage-format.md).

### Captured without a name? Use the save form

If a code was captured without a pre-typed name (for example, armed via the `learn_start` service), the capture is held as a *pending* code:

1. Go to **Settings** → **Devices & Services** → **OpenIRBlaster**
2. Click **Configure** on the device
3. The save form opens automatically while a code is pending: enter a **name** (plus optional **tags** and **notes**) and submit

You can also press **Send Last Learned** first to test the pending code before saving it.

### From scripts and automations

`learn_start` arms a learning session. With a response variable, the call waits for the outcome and hands the capture metadata back to your script:

```yaml
action: openirblaster.learn_start
data:
  config_entry_id: "01KESZQ4GF6WSK5XBAA19N96MM"
  timeout: 60
response_variable: capture
```

The response contains `status` (`received`, `timeout`, or `cancelled`) and, on success, `carrier_hz`, `pulse_count`, and `timestamp`. Without `response_variable` the call returns immediately (fire and forget).

After a successful capture, save the pending code with `save_pending`:

```yaml
action: openirblaster.save_pending
data:
  config_entry_id: "01KESZQ4GF6WSK5XBAA19N96MM"
  name: "TV Power"
  tags: "tv, living-room"
  notes: "Samsung TV power toggle"
response_variable: saved   # optional: {code_id, name, carrier_hz, pulse_count}
```

To abort a session, use `learn_cancel`. It refuses to throw away an unsaved capture unless you say so:

```yaml
action: openirblaster.learn_cancel
data:
  config_entry_id: "01KESZQ4GF6WSK5XBAA19N96MM"
  discard_pending: true   # omit (default false) to protect a pending code
```

The `config_entry_id` for all services can be picked from a dropdown in the UI action editor, and switching that action to YAML mode shows the ID itself.

## Renaming a Code

```yaml
action: openirblaster.rename_code
data:
  config_entry_id: "01KESZQ4GF6WSK5XBAA19N96MM"
  id: "tv_power"
  new_name: "Living Room TV Power"
```

The button's display name updates live. The code's `id` and the button's entity ID stay stable, so existing automations keep working.

## Deleting a Code

### From the UI

1. Go to **Settings** → **Devices & Services** → **OpenIRBlaster**
2. Click **Configure** on the device
3. Select **Manage IR Codes**
4. Pick the code from the dropdown
5. Confirm on the deletion screen

The button entity disappears immediately.

### From a service call

```yaml
action: openirblaster.delete_code
data:
  id: "tv_power"
  config_entry_id: "01KESZQ4GF6WSK5XBAA19N96MM"
```

`config_entry_id` is optional with a single blaster, but **required when more than one blaster has a code with the same id** - the service refuses to guess which one you meant.

## Sending Codes

Three ways to transmit:

1. **Code buttons** - press the button entity (or `button.press` it from an automation)
2. **Send Last Learned** - replays the current pending capture, for testing before saving
3. **The `send_code` service** - for scripts, including one-off sends of codes that are not stored:

```yaml
action: openirblaster.send_code
data:
  config_entry_id: "01KESZQ4GF6WSK5XBAA19N96MM"
  id: "tv_power"
response_variable: sent   # optional: {code_id, name, carrier_hz, pulse_count, sent: true}
```

`carrier_hz` and `pulses` can be supplied to override (or send without) a stored code.

## Automating on the Code Activity Event

The **Code Activity** event entity fires two event types:

- `code_learned` - a capture was finalized (attributes: `carrier_hz`, `pulse_count`, `timestamp`, and `rssi` when the firmware provides it)
- `code_saved` - a code was saved to the library (attributes: `code_id`, `name`, `carrier_hz`, `pulse_count`)

```yaml
automation:
  - alias: "Announce captured IR codes"
    trigger:
      - platform: state
        entity_id: event.openirblaster_code_activity
    condition:
      - condition: template
        value_template: "{{ trigger.to_state.attributes.event_type == 'code_learned' }}"
    action:
      - service: notify.mobile_app_phone
        data:
          message: >
            Captured an IR code:
            {{ trigger.to_state.attributes.pulse_count }} pulses at
            {{ trigger.to_state.attributes.carrier_hz }} Hz
```

## Automation Examples

### Turn off TV at bedtime

```yaml
automation:
  - alias: "Turn off TV at bedtime"
    trigger:
      - platform: time
        at: "23:00:00"
    action:
      - service: button.press
        target:
          entity_id: button.openirblaster_tv_power
```

### Voice Control

Use Home Assistant's voice assistants to trigger IR codes:

"Alexa, turn on the TV" -> Triggers IR code via automation

### Conditional Control

```yaml
automation:
  - alias: "Projector for movie time"
    trigger:
      - platform: state
        entity_id: media_player.living_room
        to: "playing"
    condition:
      - condition: state
        entity_id: input_boolean.movie_mode
        state: "on"
    action:
      - service: button.press
        target:
          entity_id: button.openirblaster_projector_power
```

Button entity IDs derive from your device name plus the code name; check the device page for the exact IDs on your install.

## Reconfiguring After an ESPHome Rename

If you rename the device in ESPHome, the integration's stored service binding goes stale. Instead of removing and re-adding:

1. Go to **Settings** → **Devices & Services** → **OpenIRBlaster**
2. Open the entry's menu (three dots) and choose **Reconfigure**
3. Select the (renamed) device and submit

The hardware identity is verified by MAC address: selecting a *different* blaster aborts with "wrong device" (your code library stays bound to its original hardware), and a device whose MAC sensor is unavailable aborts with a distinct message asking you to bring it fully online first.

## Repairs

The integration raises issues under **Settings** → **System** → **Repairs** for conditions you can act on:

| Issue | Meaning | Fix |
|---|---|-----|
| Firmware needs an update | The device sends a corrupted MAC in learned-code events (a bug in old firmware). Learning still works via name matching. | Update the device firmware |
| Could not identify the MAC address | Several ESPHome devices match this entry's name, so the MAC could not be back-filled unambiguously. | Run **Reconfigure** and pick the correct device |
| Cannot send IR codes | The ESPHome send service disappeared after setup (device offline or renamed). | Bring the device online, then reload or reconfigure |

Each issue clears automatically once the condition is resolved.

## Startup Housekeeping

On every startup the integration tidies up after older versions (all idempotent, no action needed):

- migrates entities off the legacy "Controls" device and removes it
- removes orphaned entity registry entries left by removed features (v1.2.1), such as the old per-code delete buttons
- back-fills the device's MAC address into entries created before MAC capture existed
- turns the device's learning mode off if a previous run was interrupted mid-session

## Storage

Learned codes are stored in `.storage/openirblaster_{entry_id}` and include:
- Display name
- Unique ID (slugified)
- Carrier frequency (typically 38kHz)
- Pulse timing array
- Timestamp

Removing the integration keeps this file from version 1.3.2 onwards; 1.3.1 and earlier deleted it with the entry. Delete it by hand once you no longer need the codes. See [When You Remove the Integration](storage-format.md#when-you-remove-the-integration).

For the full schema and a safe procedure for editing the file by hand, see [Storage Format & Manual Editing](storage-format.md).

---

*See [Troubleshooting](troubleshooting.md) for common issues and solutions.*

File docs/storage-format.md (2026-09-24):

# Storage Format & Manual Editing

> **Use case:** the integration normally writes this file for you. Edit it by hand only as a workaround when you can capture an IR signal in ESPHome logs but the integration's learning session isn't picking it up (see issue [#9](https://github.com/jaycollett/OpenIRBlaster/issues/9)).

## File Location

The integration stores all learned codes in Home Assistant's storage area:

```
<HA config>/.storage/openirblaster_<entry_id>
```

The file name has no extension. `<entry_id>` is the config entry ID, and there is one storage file per OpenIRBlaster device added to Home Assistant, so the quickest way to find yours is to list them:

```bash
ls <HA config>/.storage/openirblaster_*
```

Each file carries its own ID and device name under `data.device`, which is how you tell two blasters apart. To look an ID up first instead, `.storage/core.config_entries` lists every config entry with its integration and title, and the **Config entry** dropdown on any OpenIRBlaster action in **Developer Tools -> Actions** fills the ID in for you once you switch that action to YAML mode.

## When You Remove the Integration

From version 1.3.2, deleting an OpenIRBlaster entry in **Settings -> Devices & Services** leaves its storage file where it is. Home Assistant removes the device and its entities, and the file keeps every code, including the carrier frequency measured when each one was learned. The command-line exporter, `tools/openirblaster_to_wig.py`, can still convert it to HAIR's format after the integration is gone.

Version 1.3.1 and earlier deleted the file along with the entry. On one of those versions, export or pluck your codes first, or update before you remove anything.

Adding the same blaster again creates a new config entry with a new ID, and so a new, empty storage file. The old file stays alongside it and the integration does not read it. To bring the codes back into the new entry, copy them across with the [Safe Manual-Edit Procedure](#safe-manual-edit-procedure). Once the codes are somewhere you trust, you can delete the old file by hand.

## On-Disk Format

The file follows Home Assistant's standard storage envelope. Your code data lives inside `data`:

```json
{
  "version": 1,
  "minor_version": 1,
  "key": "openirblaster_01HZABCDEFGHIJK",
  "data": {
    "version": 1,
    "device": {
      "config_entry_id": "01HZABCDEFGHIJK",
      "name": "OpenIRBlaster",
      "device_id": "openirblaster-2ca965",
      "last_learned": {
        "name": "TV Power",
        "timestamp": "2026-04-01T12:34:56+00:00",
        "pulse_count": 8
      }
    },
    "codes": [
      {
        "id": "tv_power",
        "name": "TV Power",
        "carrier_hz": 38000,
        "pulses": [9000, -4500, 560, -560, 560, -1690, 560, -560],
        "created_at": "2026-04-01T12:34:56+00:00",
        "updated_at": "2026-04-01T12:34:56+00:00",
        "tags": [],
        "notes": ""
      }
    ]
  }
}
```

### Schema versioning

The top-level `version` / `minor_version` pair is Home Assistant's storage
envelope versioning, managed by the integration:

- `version` (major) changes only for breaking schema rewrites.
- `minor_version` changes for additive schema extensions.

Both are defined in `const.py` (`STORAGE_VERSION` / `STORAGE_MINOR_VERSION`,
currently `1` / `1`). On load, `storage.OpenIRBlasterStore._async_migrate_func`
migrates older data forward; data written by a NEWER schema than the
installed integration knows is rejected rather than silently loaded. When
editing by hand, leave both version fields exactly as you found them.

### The `device.last_learned` block

`device.last_learned` records the most recently saved code's metadata
(`name`, `timestamp`, `pulse_count`). It backs the three "Last Learned"
diagnostic sensors so their values survive Home Assistant restarts. It is
optional: absent until the first code is saved, and safe to leave untouched
(or omit) when editing by hand. Do not point it at a code that does not
exist; it is display metadata only and is overwritten on the next save.

### Code fields

| Field | Type | Required | Notes |
|---|---|---|---|
| `id` | string | yes | Lowercase slug. Must be unique within the file. Used to derive the button entity ID. **Once set, do not rename** - renaming the `id` orphans the button entity in the registry. |
| `name` | string | yes | Human-readable display name shown on the button. Safe to change. |
| `carrier_hz` | int | yes | IR carrier frequency, typically `38000`. |
| `pulses` | array of int | yes | Pulse timings in microseconds. Positive = mark (LED on), negative = space (LED off). Max 2000 elements. |
| `created_at` | ISO 8601 string | yes | UTC timestamp. |
| `updated_at` | ISO 8601 string | yes | UTC timestamp. Update this when you change the entry. |
| `tags` | array of string | yes | May be empty. |
| `notes` | string | yes | May be empty. |

## Getting Pulse Data from ESPHome Logs

When learning mode is armed, the ESPHome firmware logs the captured pulses before firing the event. In the ESPHome dashboard logs you'll see entries like:

```
[remote.raw:028]: Received Raw: 9000, -4500, 560, -560, 560, -1690, 560, -560, ...
```

The comma-separated integers are exactly the array that belongs in `pulses`. Copy them verbatim.

The carrier frequency from the same capture is what goes in `carrier_hz` (typically `38000`).

## Safe Manual-Edit Procedure

> **Important:** Home Assistant caches `.storage` contents in memory. If you edit the file while HA is running, your changes will be **overwritten the next time the integration saves** - for example when a new code is learned, renamed, or deleted. The user in [issue #9](https://github.com/jaycollett/OpenIRBlaster/issues/9) lost two remotes of manual entries this way.

Always follow this sequence:

1. **Stop Home Assistant** (full stop, not just a restart trigger from the UI - use your supervisor / `systemctl stop home-assistant` / container stop, whatever applies to your install).
2. **Back up the file** first: `cp openirblaster_<entry_id> openirblaster_<entry_id>.bak`
3. **Edit** the file with a JSON-aware editor (VS Code, Notepad++ with the JSON plugin, `jq`). Validate the JSON before saving.
4. **Start Home Assistant** again. The integration loads the file on startup and creates a button entity for each code that has a unique `id`.

If a button entity doesn't appear for a code you added, check the Home Assistant logs at startup for parsing errors from `custom_components.openirblaster.storage`.

## Adding a New Code by Hand

Append an object to the `data.codes` array. Minimum viable entry:

```json
{
  "id": "onkyo_power",
  "name": "Onkyo Power",
  "carrier_hz": 38000,
  "pulses": [9000, -4500, 560, -560, 560, -1690, 560, -560],
  "created_at": "2026-05-14T00:00:00+00:00",
  "updated_at": "2026-05-14T00:00:00+00:00",
  "tags": [],
  "notes": "Added manually from ESPHome logs"
}
```

Rules:
- `id` must be unique within `data.codes` and match `[a-z0-9_]+` (lowercase letters, digits, underscores).
- `pulses` must be a non-empty JSON array of integers, length <= 2000.
- The button entity ID derived from this code will be `button.openirblaster_<id>` (`button.openirblaster_onkyo_power` in this example).

## Editing an Existing Code

- **Renaming a button label:** change `name`, update `updated_at`. The entity ID stays the same.
- **Replacing the captured signal:** swap out `pulses` (and `carrier_hz` if needed), update `updated_at`.
- **Deleting a code:** remove its object from the `codes` array, then on next HA start the integration will clean up the orphaned button entity from the entity registry.

Do not edit `id` once a code has been used. If you must change the slug, delete the old entry and add a new one with the new ID.

## Validating Before Restart

A quick sanity check from a shell:

```bash
jq '.data.codes | length' openirblaster_<entry_id>   # number of codes
jq '.data.codes | map(.id)' openirblaster_<entry_id> # list IDs - must be unique
jq -e '.data.codes | map(.pulses | length) | max <= 2000' openirblaster_<entry_id>
```

If any of those error, fix the file before restarting Home Assistant.

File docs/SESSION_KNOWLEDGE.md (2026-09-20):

# Session Knowledge

Accumulated non-obvious learnings about this project. Read before making architectural decisions; update when something important, non-obvious, or counter-intuitive is discovered. Include dates so staleness can be assessed.

## Architecture decisions

### Two-device "Controls" layout vs unified device with entity categories (2026-06-12)

- The original two-device layout (main device + virtual "Controls" device, added 2026-01-13 in `df0bd0f`) existed to quarantine the per-code DELETE button entities that shipped at the time (one-click delete, disabled by default for safety).
- Those delete buttons were removed on 2026-01-20 (`5bcfc3a`) once the two-step options-flow delete (select, then confirm) shipped. After that, the Controls device held only benign entities.
- **A unified device with entity categories was attempted once before and abandoned due to issues, but the attempt was never committed and the specific issues are not remembered.** v1.2.0 (beta) re-attempts it with an idempotent migration that re-points entity registry entries before deleting the Controls device. Watch the beta for whatever broke last time: candidate failure modes are orphaned entities, lost customizations, duplicate devices, or surprise dashboard/voice-assistant exposure changes (categories intentionally remove entities from auto-dashboards and default Assist exposure).
- Downgrading v1.2.0 -> v1.1.0 self-heals: v1.1.0 recreates the Controls device at setup and entities re-attach (unique_ids unchanged in both directions).

### Deletion must stay a two-step process (2026-06-12)

Deliberate product decision: deleting a code always requires select-then-confirm (options flow) or an explicit service call with the exact code id. Never reintroduce one-click delete entities.

### The project pivoted to hardware-first, and the integration is deprecated (2026-09-19)

HAIR (https://github.com/DAB-LABS/HAIR, MIT, HACS default store) already did the
infrared-domain migration this project had planned, with a live sniffer, protocol
decoders, climate matrices and import from SmartIR/Flipper/LIRC/Girr. Competing was
judged a bad use of time. HAIR owns no hardware or firmware; OpenIRBlaster does, and
that is where the project continues. v1.2.4 deprecates the integration and ships the
export. The working integration code was deliberately left in place; removal is a
later decision.

### Carrier frequency survives the HAIR export, and this is time-sensitive (2026-09-19)

A `.wig.json` has no carrier field, which looks like data loss until you notice that
the second word of a Pronto preamble IS the carrier, encoded as a divisor of a fixed
reference frequency. Measured round-trip error is under 0.4% across the IR band
(36 kHz reads back 36045, 40 kHz reads back 39857). So exporting preserves every
captured carrier.

Why it is time-sensitive: ESPHome delivers no carrier through `ir_rf_proxy`
(`esphome/infrared.py` constructs `InfraredReceivedSignal(timings=...)` with no
modulation), so codes re-learned through the new platform come back at the 38 kHz
default. The existing `.storage` file is the only place those measured carriers
exist. Users must export before deleting it.

### The Pronto encoder is vendored on purpose (2026-09-19)

`custom_components/openirblaster/wig_export.py` carries its own copy of the Pronto
arithmetic rather than importing `infrared_protocols.commands.pronto`. Three reasons:
the library requires Python 3.14 and CI runs 3.12, so a dependency would make the
tool untestable in CI; the standalone script has to work for a user who already
removed the integration; and it keeps the file copyable on its own.
`tests/test_wig_export.py::test_matches_infrared_protocols_reference` asserts
byte-for-byte agreement with the reference implementation and skips where the
library is absent, so the duplication cannot drift silently.

### Pronto cannot encode an odd-length pulse array (2026-09-19)

Pronto encodes burst pairs, so a capture ending on a mark with no trailing space
raises `ValueError: pronto timing data does not match the preamble burst pair
counts`. The export appends a 38000us trailing gap and records it in the receipt
rather than padding silently. Verified against `infrared_protocols` 10.1.0.

## Release and CI mechanics

### Every master push must bump the version (2026-06-12)

- The Release workflow auto-tags and publishes a GitHub release from `manifest.json` on every master push where the tag does not already exist.
- The CI workflow's Version Check job fails any master push whose manifest version equals the latest release tag. Consequence: docs-only or fix-only commits cannot be pushed alone; bundle them with a version bump.
- Betas: the workflow always publishes a full release; flip it afterwards with `gh release edit vX.Y.Z --prerelease`. Promote with `--prerelease=false`.

### CI test environment is stricter than the local venv (2026-06-12)

- CI runs Python 3.12 with pinned requirements; the local `.venv` is Python 3.14 with a newer HA. CI's pytest-homeassistant plugin fails on lingering timers/tasks at teardown that the local environment silently allows. Local green does not guarantee CI green.
- Two incidents: (1) tests arming a learning session without cleanup leaked the `async_call_later` timeout timer (fixed with async-generator fixtures that `await session.async_cleanup()`); (2) push-based entities without `_attr_should_poll = False` made EntityPlatform schedule a poll interval timer (HA's `EventEntity`, `SensorEntity`, and `TextEntity` bases do NOT disable polling; `ButtonEntity` does).

## Home Assistant compatibility

### Options flow `config_entry` property needs HA 2024.12 (2026-06-12)

The inherited `OptionsFlow.config_entry` property only exists from HA 2024.12.0 (the 2024.11 dev blog announced it, but the property itself landed in 2024.12). v1.1.0 shipped declaring 2024.11 support and its options flow crashes there. The floor is now 2024.12.

### ESPHome service discovery must not pattern-match across entries (2026-06-12)

With two blasters where one is offline at boot, a bare `*_send_ir_raw` pattern fallback binds the offline entry to the other device's service and IR transmits from the wrong device. Discovery must exclude service names claimed by other entries and refuse ambiguous matches (raise ConfigEntryNotReady instead).

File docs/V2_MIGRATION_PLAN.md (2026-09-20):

# OpenIRBlaster v2.0 migration plan

Status: proposal, awaiting approval. No source files changed.
Written 2026-09-19 against v1.2.3 (commit 6e8f4ad, branch master, clean).

This plan moves OpenIRBlaster off its private ESPHome transport (the `esphome.openirblaster_learned` event plus the `send_ir_raw` user service) and onto Home Assistant's `infrared` entity domain. The storage layer, the code library, stable code IDs and the per-code button entities stay. Only the transport and the entity wiring around it change, plus a new presets feature layered on top.

## Verification notes, read these first

Everything below about Jay's current code was read from the working tree and carries a `file:line` reference. Everything about the new API was read from source, not from a search summary:

- `homeassistant/components/infrared/` as installed in `.venv` (HA 2026.4.3, Python 3.14.7).
- `homeassistant/components/infrared/{__init__,entity,helpers,const}.py` at tag `2026.9.0`, fetched from `raw.githubusercontent.com/home-assistant/core`.
- `homeassistant/components/esphome/infrared.py` at tags `2026.4.3` (installed) and `2026.9.0`.
- `infrared_protocols` 10.1.0, downloaded from PyPI, unpacked and imported under Python 3.14.7 for live introspection.

Three corrections to the assumptions this work started from. They change the plan, so they are up top.

### Correction 1: the receiver API did not ship in 2026.4

The brief says "require HA 2026.4+". That floor does not work. The `infrared` domain shipped in 2026.4, but at 2026.4 it was emitter only. Verified by fetching `homeassistant/components/infrared/__init__.py` at each release tag and grepping for `async_subscribe_receiver`:

| HA tag | `async_subscribe_receiver` present | `helpers.py` present | pinned library |
|---|---|---|---|
| 2026.4.0 | no | no (404) | infrared-protocols==1.1.0 |
| 2026.5.0 | no | no (404) | infrared-protocols==2.0.0 |
| 2026.6.0 | yes | yes | infrared-protocols==5.6.1 |
| 2026.7.0 | yes | yes | infrared-protocols==6.3.0 |
| 2026.8.0 | yes | yes | infrared-protocols==8.2.1 |
| 2026.9.0 | yes | yes | infrared-protocols==9.0.0 |
| dev | yes | yes | infrared-protocols==10.1.0 |

The installed 2026.4.3 copy confirms it independently: its `__all__` is exactly `["DOMAIN", "InfraredEntity", "InfraredEntityDescription", "async_get_emitters", "async_send_command"]`, there is no `entity.py`, no `helpers.py`, no `InfraredReceivedSignal` and no receiver base class anywhere in the package.

The real floor for capture is HA 2026.6.0. My recommendation is to set the floor at 2026.9.0 instead, for reasons in Correction 2.

### Correction 2: the library API moved under the domain between 2026.4 and 2026.9

`infrared-protocols` went from 1.1.0 to 10.1.0 in about five months, ten major versions. That is not cosmetic. Two breaks are visible in code I read directly:

`Command.get_raw_timings()` changed its return type. At HA 2026.4.3, `esphome/infrared.py:38-42` has to unpack timing objects:

```python
timings = [
    interval
    for timing in command.get_raw_timings()
    for interval in (timing.high_us, -timing.low_us)
]
```

At HA 2026.9.0, `esphome/infrared.py:50` just passes it through, because `get_raw_timings()` now returns a flat `list[int]` of signed microseconds:

```python
timings = command.get_raw_timings()
```

The code lookup entry point changed too. At HA 2026.4.3, `lg_infrared/entity.py` imports `make_command` as a module-level function:

```python
from infrared_protocols.codes.lg.tv import LGTVCode, make_command as make_lg_tv_command
```

At 10.1.0 there is no module-level `make_command`. The factory is a method on the enum: `LGTVCode.POWER.to_command(repeat_count=0)`. I confirmed this by importing the extracted wheel.

Both breaks land squarely on the presets feature. Targeting 2026.6 means writing against a library API two majors old with no way to pin it, because core owns the pin. Targeting 2026.9 costs users nothing real (it is the current release as of today) and gets the API shape the presets code will actually be written against.

### Correction 3: Python 3.14 is the real floor, and the project already runs it

`infrared-protocols` declares `requires-python = ">=3.14"` (verified from the PyPI JSON metadata for 10.1.0). Depending on `infrared` inherits that floor. CLAUDE.md says the project targets Python 3.12+ and `hacs.json` claims `"homeassistant": "2024.12.0"`. Both have to move.

Practically this is less painful than it sounds. HA 2026.6+ already requires Python 3.14 in its own right, so any user on a supported HA is already there, and the local `.venv` is already 3.14.7. The cost falls on CI, which `docs/SESSION_KNOWLEDGE.md` records as running Python 3.12 with pinned requirements.

Stated plainly, a v2.0 user needs: Home Assistant 2026.9.0 or newer, which implies Python 3.14, plus ESPHome 2026.1.0 or newer on the device (recommend 2026.5.0+, see the risk register).

---

## a. Current state

### The ESPHome learned event

The event name is defined once and consumed in one place.

| What | Where |
|---|---|
| Event name constant | `const.py:18` (`EVENT_LEARNED = "esphome.openirblaster_learned"`) |
| Bus subscription, armed per session | `learning.py:246-248` |
| Event handler | `learning.py:477-593` |
| MAC vs device_id filtering | `learning.py:489-567` |
| Dangling-MAC firmware repair | `learning.py:63-67`, `learning.py:499-523` |
| Payload attribute keys | `const.py:47-54` |
| Payload parse and validation | `learning.py:595-695` |
| Firmware side that fires it | `hardware/firmware/factory_flash.yaml:64-77`, `:261-266` |

The handler is 117 lines, and roughly 80 of those exist only because a bus event carries no identity. It has to decide whether the event belongs to this device by comparing a MAC that older firmware sometimes returned as garbage from a dangling `c_str()` pointer (`learning.py:63-67` documents the bug, `learning.py:499-517` detects it and raises a repair issue).

### The capture-marker replay path

A second capture path exists purely to recover events lost on a dropped ESPHome API socket. It watches a `text_sensor` whose value replays on reconnect, waits 500ms, and if no event arrived it calls a second ESPHome service to re-fire the event.

| What | Where |
|---|---|
| Marker constants and grace period | `learning.py:42-61` |
| Marker entity resolution (two strategies) | `learning.py:325-385` |
| Marker state-change handler | `learning.py:387-427` |
| Wait-then-replay task | `learning.py:429-447` |
| Replay service call | `learning.py:449-475` |
| Replay task tracking and cancellation | `learning.py:130-133`, `learning.py:697-704` |
| Double-commit guard the path forced | `learning.py:121-126`, `learning.py:611-614` |

### The send_ir_raw service call

Three call sites, all with the same shape, plus a four-layer discovery mechanism behind them.

| What | Where |
|---|---|
| Send last learned | `button.py:398-434` |
| Send a stored code | `button.py:478-511` |
| `send_code` service | `services.py:234-295` (the call itself at `:266-285`) |
| Cached service-name lookup | `helpers.py:193-209` |
| Discovery at setup, four priorities | `helpers.py:119-190` |
| Cross-entry claim tracking | `helpers.py:96-116` |
| Ambiguity error type | `helpers.py:25-31` |
| Missing-service repair pair | `helpers.py:34-59` |
| Config-flow discovery | `config_flow.py:228-281` |
| Firmware side | `hardware/firmware/factory_flash.yaml:30-43` |

`docs/SESSION_KNOWLEDGE.md` records why the claim tracking exists: with two blasters and one offline at boot, a bare `*_send_ir_raw` pattern match bound the offline entry to the other device's service and transmitted from the wrong hardware.

### carrier_hz

Present in 15 files or call chains. Full inventory:

- Storage schema and writes: `storage.py:133`, `:146`, `:166`, `:179-180`
- Capture model and validation: `learning.py:76`, `:588`, `:598`, `:632-650`, `:681`
- Sends and button construction: `button.py:95`, `:121`, `:339`, `:420`, `:445`, `:451`, `:496`
- Services: `services.py:77`, `:192`, `:245`, `:254`, `:271`, `:291`, `:413`, `:446`
- Options flow save and its form text: `config_flow.py:534`, `:579`
- Event entity attributes: `event.py:112`, `:129`
- Diagnostics: `diagnostics.py:58`
- User-visible strings: `strings.json:45`, `:158`
- Service schema bounds (30000 to 56000 Hz): `services.yaml:47-54`
- Firmware default and plumbing: `factory_flash.yaml:5`, `:119`, `:243`, `:266`

Today it is required and validated as a positive int (`learning.py:644-650`), and the notification text prints it (`learning.py:723`).

### The learning state machine

States are string constants at `const.py:25-30`, the 30 second default at `const.py:21`.

| Transition | Where |
|---|---|
| Entry point, terminal-state reset, synchronous ARMED claim | `learning.py:175-280` |
| Timeout scheduling via `async_call_later` | `learning.py:273-275` |
| Listener and timeout teardown, idempotent | `learning.py:282-298` |
| Capture commit, IDLE/ARMED to RECEIVED | `learning.py:672-695`, `learning.py:706-742` |
| Timeout handler, ARMED to TIMEOUT | `learning.py:744-792` |
| User cancel, ARMED to CANCELLED | `learning.py:794-816` |
| Validation cancel, ARMED to CANCELLED | `learning.py:818-853` |
| Reset to IDLE | `learning.py:855-877` |
| Unload cleanup | `learning.py:879-904` |
| Callback fan-out to entities | `learning.py:146-173` |

The one-session lock is two things working together. First, exactly one `LearningSession` object is constructed per config entry (`__init__.py:356-362`, held at `data.py:23`), so "one session per device" is really "one session per config entry". Second, the ARMED claim at `learning.py:218` is set before the first `await`, so a concurrent `async_start_learning` hits the rejection at `:190-194` rather than overwriting the first session's unsubscribe callable.

The device also has a hardware-level arm step: a `switch` entity that puts the firmware into learning mode. Turned on at `learning.py:231-243`, off at `learning.py:313-323` with five call sites, resolved at config time by `config_flow.py:174-226`, and force-reset at setup if a previous run left it on (`__init__.py:420-453`).

### Module map, current

| Module | Lines | Role |
|---|---|---|
| `__init__.py` | 496 | Setup, MAC back-fill, device registry, legacy migrations, orphan sweep |
| `learning.py` | 904 | State machine, event listener, replay path, timeout |
| `config_flow.py` | 677 | ESPHome device discovery, reconfigure, options flow (save, delete) |
| `button.py` | 512 | Learn, send-last, per-code buttons |
| `services.py` | 481 | Six integration services |
| `sensor.py` | 239 | Three last-learned diagnostic sensors |
| `storage.py` | 271 | JSON persistence, slug IDs, migration hook |
| `helpers.py` | 209 | ESPHome service discovery, repairs, entity cleanup |
| `event.py` | 133 | `code_activity` event entity |
| `text.py` | 103 | Code Name input |
| `diagnostics.py` | 91 | Redacted entry dump |
| `data.py` | 30 | Runtime dataclass |
| `const.py` | 84 | Constants |

Tests: 137 test functions across 12 files, 4,192 lines.

---

## b. Target state

### Module fate

| Module | Fate |
|---|---|
| `storage.py` | Survives, extended. Schema v1 to v2, `carrier_hz` nullable, new `source` and `preset` fields |
| `learning.py` | Survives, roughly halved. Event listener, marker/replay path, MAC filtering and switch control all go; subscription lifecycle replaces them |
| `button.py` | Survives, transport swapped. `CodeButton` and `SendLastButton` call `async_send_command` |
| `services.py` | Survives, transport swapped in `send_code`, new `add_preset` service |
| `config_flow.py` | Heavily rewritten. Emitter and receiver entity pickers replace ESPHome device discovery. New preset-picker options steps |
| `sensor.py` | Survives unchanged in shape |
| `event.py` | Survives, `carrier_hz` attribute becomes nullable |
| `text.py` | Survives unchanged |
| `diagnostics.py` | Survives, new fields |
| `data.py` | Survives, `esphome_service_name` field replaced by emitter/receiver entity IDs |
| `helpers.py` | Mostly deleted. Everything ESPHome-specific goes; `async_remove_code_entities` stays |
| `__init__.py` | Survives, shrinks. MAC back-fill and service discovery go; a config-entry migration is added |
| `commands.py` | New. `RawCommand`, the `Command` subclass that carries stored pulses |
| `presets.py` | New. Codeset enumeration and preset-to-command resolution |

### The send path

`infrared.async_send_command(hass, entity_id, command, context=None)` takes an `infrared_protocols.commands.Command`, not raw timings. Verified at HA 2026.9.0 `infrared/helpers.py:35-66`. So the integration needs a `Command` subclass that carries a stored pulse array verbatim.

`Command` is a plain ABC with no machinery (verified, `infrared_protocols/commands/__init__.py` at 10.1.0):

```python
class Command(abc.ABC):
    repeat_count: int
    modulation: int
    def __init__(self, *, modulation: int, repeat_count: int = 0) -> None: ...
    @abc.abstractmethod
    def get_raw_timings(self) -> list[int]: ...
```

So a new `commands.py` holds roughly this:

```python
DEFAULT_MODULATION_HZ = 38000

class RawCommand(Command):
    """A stored pulse array replayed verbatim."""

    def __init__(self, timings, *, modulation=None, repeat_count=0):
        super().__init__(
            modulation=modulation or DEFAULT_MODULATION_HZ,
            repeat_count=repeat_count,
        )
        self._timings = list(timings)

    def get_raw_timings(self):
        return list(self._timings)
```

The sign convention already matches. Both `Command.get_raw_timings` and the stored `pulses` array use positive microseconds for mark and negative for space (`docs/storage-format.md`, code fields table), so no transformation is needed.

There is an alternative worth naming and rejecting. `infrared_protocols.commands.pronto.ProntoCommand.from_raw_timings(timings, modulation=None)` exists and does exactly this job, defaulting to 38000 Hz when modulation is None. I tested a round trip under Python 3.14.7 with the extracted 10.1.0 wheel:

```
in:  [9000, -4500, 560, -560, 560, -1690, 560, -560, ...]
out: [8993, -4523, 552,  -605, 552, -1709, 552,  -605, ...]
```

Worst-case drift 45µs per interval, and `cmd.modulation` reads back as 38029 rather than 38000, because Pronto quantizes timings against a fixed reference frequency. NEC decoding tolerance in the same library is 40 percent (`commands/nec.py:15`), so it would probably work. It is still a lossy round trip on data that used to be replayed byte for byte, on a feature whose whole value is byte-for-byte fidelity. Use `RawCommand`. Keep `ProntoCommand` in mind only if a future import/export feature wants a portable text format.

### The capture path and the state machine

`async_subscribe_receiver(hass, entity_id_or_uuid, signal_callback) -> CALLBACK_TYPE` (verified, HA 2026.9.0 `infrared/helpers.py:69-105`). It raises `HomeAssistantError` with translation key `receiver_not_found` when the entity is missing or is not an `InfraredReceiverEntity`, and `component_not_loaded` when the domain is not set up. The callback receives `InfraredReceivedSignal(timings: list[int], modulation: int | None = None)` (verified, `infrared/entity.py:30-35`).

Nothing is fired on the event bus. The receiver's own state does change to a new timestamp on every capture, so a YAML automation can see that a signal arrived, but the timings are not in the state or in any attribute.

State mapping:

| State | Today | Under v2 |
|---|---|---|
| IDLE | No listeners, no timeout | Same. No subscription held |
| IDLE to ARMED | Claim state, turn on the firmware switch, subscribe to the bus, resolve and subscribe to the marker sensor, schedule `async_call_later` | Claim state (unchanged, still before the first await), call `async_subscribe_receiver` on the selected receiver, schedule `async_call_later`. No switch, no marker |
| ARMED to RECEIVED | Filter the event by MAC or device_id, parse `pulses_json`, validate carrier, commit | Callback fires with an already-typed `InfraredReceivedSignal`. Validate length only, commit |
| ARMED to TIMEOUT | Teardown, switch off, notify | Teardown, notify. No switch |
| ARMED to CANCELLED | Teardown, switch off, notify | Teardown, notify. No switch |
| RECEIVED to SAVED | Storage write, dispatcher signal | Unchanged |
| any to IDLE | `async_clear_pending` | Unchanged |

Where the subscription lives: created inside `async_start_learning` immediately after the ARMED claim, stored on the session as `self._unsub_receiver`, released in `_teardown_listeners_and_timeout` (`learning.py:288-298` today). That is the same lifetime the bus listener has now, so the teardown call sites do not move.

I am deliberately not using `InfraredReceiverConsumerEntity` (HA 2026.9.0 `infrared/helpers.py:174-229`), even though the research report recommends it. It is an `Entity` base that subscribes for the entity's whole lifetime and manages resubscription on receiver availability changes. OpenIRBlaster wants a subscription that exists only during a 30 second armed window, so a permanently subscribed entity would have to filter out every stray IR signal in the room and would defeat the timeout. The direct helper is the right fit. What is worth borrowing from the consumer base is its availability handling: track the receiver entity's state with `async_track_state_change_event` while armed, and fail the session with a clear reason if the receiver goes unavailable mid-window rather than silently timing out.

The 30 second timeout mechanism does not change. `async_call_later` at `learning.py:273-275` is transport-agnostic, and the `_capture_finalized` guard at `learning.py:754` that prevents a capture landing at the deadline from being stomped by the timeout path stays exactly as it is.

### The new locking model

This is the one place where the design genuinely has to change rather than shrink.

Today the lock is implicit. One config entry means one ESPHome device means one `send_ir_raw` service and one learning switch. Under the infrared domain, a config entry selects an emitter entity and a receiver entity from a pool. Several OpenIRBlaster entries may point at the same receiver, and a single device advertising both capabilities produces two separate `infrared` entities.

Three locking layers, stated explicitly:

1. Per-entry session lock. Unchanged. The synchronous ARMED claim before the first await (`learning.py:218`) still rejects a second concurrent start on the same entry.

2. Per-receiver exclusivity, new. Two entries armed against the same receiver would both receive every signal and both commit it, so two codes get saved from one button press. The fix is a module-level registry in `hass.data[DOMAIN]["armed_receivers"]`, a `dict[str, str]` mapping receiver entity ID to the entry ID holding it. `async_start_learning` claims the receiver synchronously in the same block as the ARMED state claim, and fails with a `ServiceValidationError` naming the conflicting entry when it is already held. The teardown releases it. Because the claim and the state claim happen in the same synchronous block, there is no window between them.

3. Emitter concurrency, none needed. Sends are fire and forget and the emitter serializes them itself. Nothing to guard.

One consequence worth stating: a user who wants two entries against one physical blaster (say, one library per room) can now do that, and learning on one blocks learning on the other for the duration of the window. That is correct behavior, and the error message should say so.

---

## c. Storage schema migration

### Version bump

`STORAGE_VERSION` goes 1 to 2 (`const.py:35`). `STORAGE_MINOR_VERSION` resets to 1 (`const.py:36`). The migration goes in `OpenIRBlasterStore._async_migrate_func` (`storage.py:33-59`), which today is an identity function that rejects anything it does not recognize.

Major rather than minor because `carrier_hz` changes from required to nullable, and a v1.x integration reading a v2 file would hit `code[ATTR_CARRIER_HZ]` at `button.py:95` and crash on a `None`. The rejection branch at `storage.py:54-59` already prevents that, and bumping major is what makes it fire.

### Field changes

Per code object:

| Field | v1 | v2 | Migration |
|---|---|---|---|
| `id` | string, required | unchanged | untouched |
| `name` | string, required | unchanged | untouched |
| `carrier_hz` | int, required, > 0 | `int \| None` | existing values preserved verbatim |
| `pulses` | list[int], required, max 2000 | `list[int] \| None` | preserved; None only for preset codes |
| `created_at`, `updated_at` | ISO string | unchanged | untouched |
| `tags`, `notes` | list / string | unchanged | untouched |
| `source` | absent | `"learned" \| "preset"` | back-filled to `"learned"` for every existing code |
| `preset` | absent | object or absent | never present after migration |

Per device block: unchanged. `config_entry_id`, `name`, `device_id`, `last_learned` all stay. `device_id` becomes vestigial once ESPHome discovery is gone, but leaving it costs nothing and removing it would break `docs/storage-format.md` for no gain.

The migration function body:

```python
async def _async_migrate_func(self, old_major_version, old_minor_version, old_data):
    if old_major_version > STORAGE_VERSION:
        raise ValueError(...)  # existing forward-incompatible guard

    data = old_data
    if old_major_version < 2:
        for code in data.get("codes", []):
            code.setdefault(ATTR_SOURCE, SOURCE_LEARNED)
        data["version"] = 2

    return data
```

Note it is `setdefault`, not assignment, and it does not touch `carrier_hz`. Nothing is dropped and nothing is rewritten. A v1 file that has been hand-edited per `docs/storage-format.md` migrates cleanly as long as it is valid v1. This is also idempotent, so a partially migrated file (interrupted write) converges.

### How carrier_hz becomes nullable without breaking existing entries

Nullability is a read-side change, not a write-side one. Existing entries keep their captured integer and keep sending at it, because `RawCommand(timings, modulation=code["carrier_hz"])` passes the stored value straight through. New captures from the infrared path store `None` and `RawCommand` substitutes 38000.

The read sites that need a None guard:

- `button.py:95`, `:121`, `:445-451`, `:496`: `CodeButton` takes `carrier_hz` positionally and hands it to the service call. Change the type to `int | None` and pass it to `RawCommand`.
- `services.py:77`: `vol.Optional(ATTR_CARRIER_HZ): cv.positive_int` stays as-is, since an explicit override is still a positive int when supplied.
- `services.py:254`, `:271`, `:291`: already uses `.get()` with a None default, so only the downstream call changes.
- `event.py:112`, `:129`: attribute becomes nullable. No code change needed, the dicts already tolerate None.
- `diagnostics.py:58`: already `.get()`.
- `strings.json:45`: the options-flow save form prints `Carrier: {carrier_hz} Hz`. Needs a variant for the unknown case, or set the placeholder to "38 kHz (default)" when None.
- `learning.py:632-650`: the whole carrier coercion and validation block goes away. `InfraredReceivedSignal.modulation` is already `int | None`.

### Preset codes in storage

A preset code is a stored code with `source: "preset"`, `pulses: null`, `carrier_hz: null`, and a `preset` object that names the library symbol:

```json
{
  "id": "living_room_tv_power",
  "name": "Living Room TV Power",
  "source": "preset",
  "carrier_hz": null,
  "pulses": null,
  "preset": {
    "module": "infrared_protocols.codes.lg.tv",
    "enum": "LGTVCode",
    "member": "POWER",
    "library_version": "10.1.0"
  },
  "created_at": "...",
  "updated_at": "...",
  "tags": [],
  "notes": ""
}
```

Timings are resolved at send time, never stored. Storing them would freeze a snapshot of whatever the library said on the day the preset was added, and would silently diverge from the library on every HA upgrade. Resolving at send time means an upstream fix to a brand's codes reaches the user for free.

Whoever reads a code decides by `source`. Learned codes go through `RawCommand`, preset codes go through `presets.resolve()`. One dispatch point in `commands.py` and every caller stays the same shape.

### Code IDs stay stable

The rule does not change: `_generate_unique_id` (`storage.py:211-227`) slugifies the original name and appends `_2`, `_3` on collision, and rename only touches `name` (`storage.py:177-178`). The entity unique ID is `{entry_id}_{code_id}` (`const.py:79`), and `SIGNAL_CODE_RENAMED` updates the button's display name in place (`button.py:470-476`).

Preset codes use the same generator against the user-supplied display name. The library symbol lives in the `preset` object and never leaks into the ID, so the same preset added under two names gets two independent IDs, and re-picking a different library command for the same code (should that ever be supported) does not orphan the entity.

---

## d. Presets

This section is written against `infrared_protocols` 10.1.0, which I downloaded, unpacked and imported under Python 3.14.7. Every claim here was executed, not read. What I could not verify is which version core will pin when Jay actually ships, which is the one real uncertainty and is in the risk register.

### What is actually in the library

Measured, not estimated:

- 17 brand directories under `infrared_protocols/codes/`: dyson, edifier, general_electric, generic, lg, marantz, nec, nedis, osram, panasonic, persang, philips, pioneer, samsung, sharp, sony, vizio.
- 39 enum classes across those brands.
- 37 of them expose `to_command`. The two that do not are `edifier.models.EdifierCommandSet` and `edifier.models.EdifierModel`, which are `StrEnum` mapping tables rather than code tables and must be filtered out.
- 1,178 enum members across the 37 usable classes. Per brand: lg 222, vizio 161, sony 152, generic 131, edifier 116, marantz 68, nec 50, samsung 49, philips 45, panasonic 36, pioneer 36, sharp 30, osram 24, persang 21, dyson 18, nedis 11, general_electric 8.

### Enumeration, with a trap

`pkgutil.iter_modules` and `pkgutil.walk_packages` both return an empty list for `infrared_protocols.codes`. I verified this. The brand directories have no `__init__.py`, so they are namespace packages, and pkgutil's file finder only reports a subdirectory as a package when it contains an `__init__` file.

`importlib.resources` works:

```python
import importlib
import importlib.resources as res

root = res.files("infrared_protocols.codes")
brands = sorted(p.name for p in root.iterdir() if p.is_dir() and not p.name.startswith("__"))
# then walk each brand dir for *.py, import, and collect Enum subclasses
# whose __module__ matches and which have a `to_command` attribute
```

That is the enumeration I ran to get the numbers above. It is filesystem traversal of someone else's package layout, which is not a supported API. Cache the result in `hass.data` on first use and treat a traversal failure as "no presets available" rather than a setup failure.

### Calling to_command

Five distinct signatures exist across the 37 classes:

| Signature | Classes |
|---|---|
| `(self) -> Command` | 8 |
| `(self, repeat_count: int = 0) -> Command` | 25 |
| `(self, repeat_count: int = 0, *, toggle: int = 0) -> Command` | 2 |
| `(self, switch: int = 1) -> Command` | 1 |
| `(self) -> Command` (string-annotated) | 1 |

So the resolver calls `member.to_command()` with no arguments, always. Every signature has defaults for everything. Do not pass `repeat_count` positionally or by keyword, because eight classes do not accept it. If repeat support is wanted later, inspect the signature first.

Verified working, end to end:

```python
>>> from infrared_protocols.codes.lg.tv import LGTVCode
>>> cmd = LGTVCode.POWER.to_command()
>>> type(cmd)
<class 'infrared_protocols.commands.nec.NECCommand'>
>>> cmd.modulation, cmd.repeat_count, len(cmd.get_raw_timings())
(38000, 0, 67)
```

### The picker flow

Three options-flow steps, a new branch from the existing menu at `config_flow.py:496-499`:

1. `async_step_add_preset_brand`: dropdown of the 17 brand names, title-cased for display.
2. `async_step_add_preset_device`: dropdown of enum classes within the brand, labeled by module and class (`lg.tv / LGTVCode`). Brands with one class skip straight through.
3. `async_step_add_preset_command`: dropdown of the members, plus a required `name` text field defaulting to a humanized member name (`POWER_ON` becomes "Power On"). Same duplicate-name check as the save path (`storage.py:122-128`).

On submit, write the code with `source: "preset"` and dispatch `SIGNAL_CODE_ADDED` (`const.py:73`), which already causes the button platform to add a `CodeButton` and the sensors to refresh (`button.py:110-133`). No entry reload.

A parallel `openirblaster.add_preset` service takes `config_entry_id`, `brand`, `device`, `command`, `name` so scripts can bulk-add.

### What happens when the pinned library changes

The failure mode is a stored `preset` object whose module, enum class or member no longer exists after a HA upgrade.

`presets.resolve(preset)` returns a `Command` or raises `PresetUnavailable`. On failure:

- `CodeButton.async_press` logs the specific missing symbol and raises a repair issue (translation key `preset_unavailable`) naming the code and the symbol. It does not crash the entity or the entry.
- The button stays registered and stays visible. Deleting it automatically would destroy the user's name, tags and notes over what may be a transient packaging problem.
- Diagnostics lists unresolvable presets so a bug report carries the evidence.
- The stored `library_version` is informational only, recorded at add time so a support conversation can compare it against the running pin. It is never used to gate resolution.

An HA upgrade that changes the codeset should not reload or rewrite storage. Resolution is lazy, at send time, and that is the whole point.

---

## e. Entity model

### What changes

| Entity | Today | Under v2 |
|---|---|---|
| Learn button (`button.py:159-377`) | Reads Code Name text, arms the session, auto-saves | Same behavior. Also unavailable when the configured receiver is missing or unavailable |
| Send Last button (`button.py:380-434`) | Calls `esphome.<device>_send_ir_raw` | Calls `infrared.async_send_command` with a `RawCommand` |
| Per-code button (`button.py:437-511`) | Holds `carrier_hz` and `pulses`, calls the ESPHome service | Holds the code dict, dispatches on `source`, calls `async_send_command`. Unavailable when the emitter is unavailable |
| Last-learned sensors (`sensor.py`) | Three diagnostic sensors, storage-backed | Unchanged |
| Code Name text (`text.py`) | Input for the Learn button | Unchanged |
| `code_activity` event (`event.py`) | `code_learned` and `code_saved` | Unchanged shape. `carrier_hz` attribute becomes nullable, a `source` attribute is added to `code_saved` |

### Availability

This is genuinely new. Today entities are always available, and a dead device surfaces as a repair issue after a failed send (`helpers.py:34-53`). Under v2 the emitter and receiver are real HA entities with real states, so availability is observable up front.

Borrow the pattern from `infrared/helpers.py:111-141` (`InfraredConsumerEntity._async_track_availability`) rather than the base class itself: set initial availability from `hass.states.get(emitter_entity_id)`, then `async_track_state_change_event` on it, flipping `_attr_available` when it crosses `unavailable`. Send buttons track the emitter, the Learn button tracks the receiver. That replaces the `esphome_service_missing` repair entirely, and it is a better experience: the button greys out before the user presses it.

### Selecting among several emitters and receivers

`async_get_emitters(hass)` and `async_get_receivers(hass)` each return a list of entity IDs and return `[]` when the domain is not loaded (verified, HA 2026.9.0 `infrared/__init__.py:78-103`). They are filtered by `isinstance` against the two base classes, so a device advertising both capabilities appears in both lists as two distinct entities.

Selection is a user decision made in the config flow, not a heuristic. Two entity IDs are stored in entry data and that is the binding. No pattern matching, no fuzzy device-registry search, none of the machinery at `helpers.py:119-190` that exists today purely because ESPHome service names had to be guessed. That is the single biggest simplification in this migration.

The emitter and receiver do not have to be the same physical device, and the config flow should not require it. A user with a receiver near the couch and a blaster behind the TV is a legitimate setup.

Both selectors use `EntitySelector(EntitySelectorConfig(domain="infrared", device_class=...))`, which is how `lg_infrared/config_flow.py` does it. `InfraredDeviceClass` is `EMITTER` / `RECEIVER` (verified, `infrared/entity.py:23-27`) and the base classes set `_attr_device_class` automatically (`entity.py:46`, `:106`), so the device-class filter is reliable.

---

## f. Config flow
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

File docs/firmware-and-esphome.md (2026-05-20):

# Firmware & ESPHome

This page covers firmware installation and ESPHome configuration for OpenIRBlaster devices, including the requirements for integration compatibility.

---

## Firmware Installation

### Option 1: Pre-built Binary (Easiest)

A pre-compiled binary is available for ESP8266 devices. No build tools required.

1. Download `factory_flash.bin` from [releases](https://github.com/jaycollett/OpenIRBlaster/releases)
2. Flash using [ESPHome Web Flasher](https://web.esphome.io/) or esptool:
   ```bash
   esptool.py write_flash 0x0 factory_flash.bin
   ```
3. Connect to "OpenIRBlaster Setup" WiFi hotspot and configure your network
4. The device will appear in Home Assistant's ESPHome integration for adoption

### Option 2: Build from ESPHome YAML

If you prefer to compile the firmware yourself or want to customize it:
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

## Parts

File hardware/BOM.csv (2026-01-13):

Component Type | Value | Designator | Footprint | Part Details
SMT Capacitor | 0.1uF | X1 C3 C4 | C0805
SMT Resistor | 5.1K | R1 R2 | M0805 | RC0805FR-075K1L
SMT Resistor | 10k | R11 R13 R14 R16 R17 | M0805
SMT Capacitor | 10uF | C1 | C0805 | GRM21BR61C106KE15K
SMT Capacitor | 22uF | C2 | C0805 | GRM21BR61A226ME51K
SMT Resistor | 39ohm | R3 R4 R5 R6 R7 R8 R9 R10 | R1210 | RC1210FR-0739RL
SMT Resistor | 220Ohm | R12 | M0805 | RC0805FR-07220RL
Connector | USB Power Port | J1 | ADAFRUIT_4907 | 4907
Voltage Regulator | 3.3V | U1 | SOT230P700X180-4N | AZ1117IH-3.3TRG1
MOSFET | IRLML6344TRPBF | Q1 | SOT23 | IRLML6344TRPBF
SMT Resistor | Zero Ohm | R15 | R1210 | RMCF1210ZT0R00
MCU | ESP8266 | MCU | ESP-12F | ESP-12F
TH 5MM LED | IR (940nm) | LEDX | TH | IR333-A
IR Receiver | 38kHz | A1 | TH | TSOP38238

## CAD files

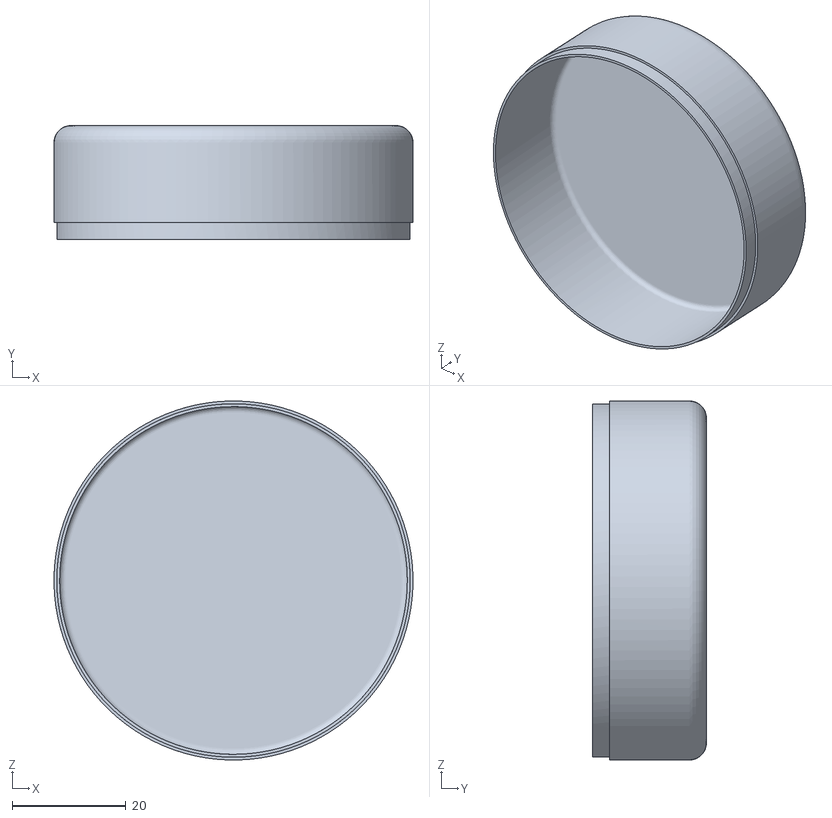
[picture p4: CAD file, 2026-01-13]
hardware/3DPrinterFiles/Top.stl
63.0 x 20.0 x 63.0

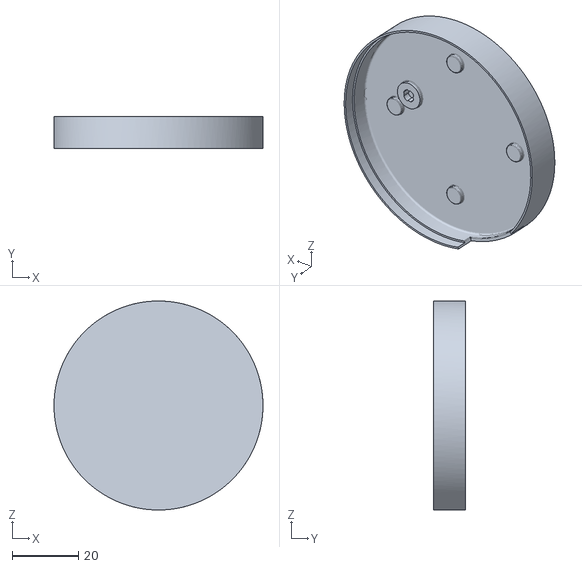
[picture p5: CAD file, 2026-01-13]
hardware/3DPrinterFiles/Bottom.stl
63.0 x 9.67 x 63.0

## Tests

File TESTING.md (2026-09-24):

# OpenIRBlaster Local Testing Guide

## ✅ Installation Complete

The integration has been installed to: `/mnt/ha_config/custom_components/openirblaster/`

## Step 1: Restart Home Assistant

**Option A: Via UI**
1. Go to **Settings → System → Restart**
2. Wait for HA to come back online (~30-60 seconds)

**Option B: Via Command Line**
```bash
# If using Docker
docker restart homeassistant

# If using systemd
sudo systemctl restart home-assistant@homeassistant
```

## Step 2: Add the Integration

1. Go to **Settings → Devices & Services**
2. Click **+ Add Integration** (bottom right)
3. Search for **"OpenIRBlaster"**
4. Click on it to start setup

### Setup Form

You'll need to provide:
- **ESPHome Device Name**: The name of your ESP device (e.g., `openirblaster-64c999`)
  - Check ESPHome dashboard or your `hardware_config/factory_config.yaml` for the name
- **Device ID** (optional): Defaults to device name if not provided
- **Learning Switch Entity ID** (optional): Auto-generated as `switch.{device}_ir_learning_mode`

**Example:**
```
ESPHome Device Name: openirblaster-64c999
Device ID: (leave blank, will use device name)
Learning Switch Entity ID: (leave blank, will auto-detect)
```

## Step 3: Verify Installation

After adding the integration, you should see:

### Entities Created
1. **button.openirblaster_{device}_learn** - Start learning session
2. **button.openirblaster_{device}_send_last** - Send last learned code (debug)
3. **sensor.openirblaster_{device}_last_learned_name** - Last learned code info
4. **sensor.openirblaster_{device}_last_learned_timestamp** - When last learned
5. **sensor.openirblaster_{device}_last_learned_pulse_count** - Pulse count

### Services Available
- `openirblaster.learn_start` - Start learning programmatically
- `openirblaster.send_code` - Send a stored code
- `openirblaster.delete_code` - Delete a code
- `openirblaster.rename_code` - Rename a code

## Step 4: Test Learning Workflow

### 4.1 Start Learning
1. Find the **"Learn IR Code"** button entity in your device page
2. Press it
3. The learning switch on your ESP device should turn on (check ESPHome logs)

### 4.2 Capture IR Code
1. Point your remote at the IR receiver
2. Press a button on your remote
3. The ESP device will capture the code and send an event to HA
4. Learning mode will automatically turn off

### 4.3 Save the Code
1. Go to **Settings → Devices & Services → OpenIRBlaster → Configure**
2. You should see a form to save the pending code
3. Enter:
   - **Code Name**: Descriptive name (e.g., "TV Power", "Volume Up")
   - **Tags** (optional): Comma-separated tags (e.g., "tv, samsung")
   - **Notes** (optional): Additional notes
4. Click **Submit**

### 4.4 Verify Code Saved
1. A new button entity should appear: `button.openirblaster_{device}_{code_id}`
2. The entity will be named after your code (e.g., "TV Power")
3. Check **Developer Tools → States** to see all entities

### 4.5 Test Transmission
1. Press the newly created button entity
2. Your TV (or device) should respond to the IR command
3. Check the logs for any errors

## Step 5: Monitor Logs

### Real-time Logs
```bash
./view_logs.sh
```

### Or manually
```bash
# View log file
tail -f /mnt/ha_config/home-assistant.log | grep openirblaster

# Docker logs
docker logs -f homeassistant 2>&1 | grep openirblaster
```

### What to Look For

**Successful Integration Load:**
```
INFO custom_components.openirblaster: Setting up OpenIRBlaster integration for entry ...
INFO custom_components.openirblaster: OpenIRBlaster integration loaded successfully
```

**Learning Session:**
```
INFO custom_components.openirblaster.learning: Starting learning session for device openirblaster-64c999
INFO custom_components.openirblaster.learning: Learned code captured: 38000 Hz, 67 pulses
```

**Code Saved:**
```
INFO custom_components.openirblaster.storage: Added code TV Power (tv_power)
```

**Code Sent:**
```
INFO custom_components.openirblaster.button: Sent code tv_power
```

## Step 6: Test Automation (Optional)

Create a simple automation to test the integration:

```yaml
automation:
  - alias: "Test OpenIRBlaster"
    trigger:
      - platform: state
        entity_id: input_boolean.test_ir
        to: "on"
    action:
      - service: openirblaster.send_code
        data:
          config_entry_id: "YOUR_ENTRY_ID"  # Get from UI or logs
          code_id: "tv_power"
```

## Troubleshooting

### Integration Not Appearing
1. Check logs for errors: `./view_logs.sh`
2. Verify manifest.json is valid
3. Ensure all Python files are present
4. Restart HA again

### ESPHome Device Not Found
1. Verify device is online in ESPHome dashboard
2. Check device name matches exactly (case-sensitive)
3. Ensure ESPHome integration is working in HA
4. Check entity ID: `switch.{device}_ir_learning_mode` exists

### Learning Not Working
1. Check ESPHome logs for IR receiver activity
2. Verify learning switch turns on (check ESPHome dashboard)
3. Point remote directly at IR receiver (TSOP38238 on GPIO4)
4. Try different remote or button
5. Check event in Developer Tools → Events → Listen for `esphome.openirblaster_learned`

### Codes Not Saving
1. Check options flow in integration settings
2. Look for errors in HA logs
3. Verify storage file: `/mnt/ha_config/.storage/openirblaster_*`
4. Check permissions on .storage directory

### Transmission Not Working
1. Verify ESPHome service exists: `esphome.{device}_send_ir_raw`
2. Check logs for service call errors
3. Test service manually in Developer Tools → Services
4. Ensure IR LED is connected to GPIO14

## Updating the Integration

After making code changes:

```bash
./update_integration.sh
```

Then restart Home Assistant.

## Useful Commands

```bash
# Update integration
./update_integration.sh

# Watch logs
./view_logs.sh

# Check integration files
ls -la /mnt/ha_config/custom_components/openirblaster/

# View storage
cat /mnt/ha_config/.storage/openirblaster_*

# Check ESPHome device
# (from ESPHome dashboard or logs)
```

## Getting Help

If you encounter issues:

1. **Check Logs**: Always start with the logs
2. **Verify Device**: Ensure ESPHome device is responding
3. **Test Manually**: Use Developer Tools to test services directly
4. **Check Events**: Listen for `esphome.openirblaster_learned` events
5. **Storage**: Verify the `.storage/openirblaster_*` file exists and is valid JSON

## Next Steps

Once basic learning/sending works:
1. Learn codes for all your remotes
2. Create automations using the codes
3. Group buttons in dashboards
4. Use services in scripts
5. Share feedback and any issues found!

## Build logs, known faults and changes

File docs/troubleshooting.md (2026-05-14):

# Troubleshooting

This page covers common issues and solutions for the OpenIRBlaster.

## Power & Connection Issues

### Device won't power on
- **Check USB-C cable**: Some cables are charge-only. Try a different cable.
- **Verify power source**: Ensure your USB power source provides at least 1A at 5V.
- **Inspect solder joints**: Cold solder joints on the USB-C connector or AZ1117 regulator are common culprits.

### Device powers on but won't connect to WiFi
- **Check credentials**: Double-check your WiFi SSID and password in the ESPHome configuration.
- **2.4GHz only**: The ESP8266 only supports 2.4GHz networks, not 5GHz.
- **Signal strength**: Move the device closer to your router during initial setup.

### ESPHome can't find the device
- **Same network**: Ensure your computer running ESPHome is on the same network as the device.
- **mDNS issues**: Some routers block mDNS. Try using the device's IP address directly.
- **Firewall**: Check that your firewall allows traffic on port 6053 (ESPHome native API).

## IR Transmission Issues

### Device doesn't control my equipment
- **Line of sight**: Ensure at least one of the IR LEDs has clear line of sight to the target device.
- **Learn the codes**: Use the IR receiver to learn your device's specific codes rather than using generic ones.
- **Carrier frequency**: Most devices use 38kHz, but some use 36kHz or 40kHz.
- **Remote is RF, not IR**: Many modern remotes (Samsung One Connect, Roku Voice, some Apple TV remotes, all BT/RF universal remotes) do not emit IR at all. Verify your remote actually emits IR by pointing it at any phone camera in video mode and pressing a button - if you don't see a faint purple/white flash on the LED, the remote is RF or Bluetooth and OpenIRBlaster cannot capture it.

### IR transmission is weak or intermittent
- **Check LED orientation**: Ensure IR LEDs are installed with correct polarity (longer leg = anode).
- **MOSFET solder joint**: Verify the IRLML6344 MOSFET has good solder connections.
- **Power supply**: Weak IR can indicate insufficient current. Each LED draws ~100mA when transmitting.

### Verifying IR LED operation
- **Cellphone camera trick**: If you're unsure whether the IR LEDs are actually working, use your cellphone camera in video mode while transmitting a code. The camera sensor can detect IR light that's invisible to the naked eye - you'll see a faint purple/white glow from the LEDs when they're transmitting.

### IR receiver not learning codes
- **Distance**: Hold your remote 2-6 inches from the receiver during learning.
- **Direct aim**: Point the remote directly at the TSOP38238 receiver.
- **Check logs**: Monitor ESPHome logs to see if any signal is being received.
- **Interference**: Fluorescent lights and sunlight can interfere with IR reception.
- **Confirm the remote emits IR**: See the camera trick above. RF and Bluetooth remotes cannot be captured.
- **ESPHome sees the code but the integration doesn't react**: This indicates the `esphome.openirblaster_learned` event reached HA but the integration's learning session wasn't armed when it fired (timeout, state mismatch, or the device's `mac_address` doesn't match what was stored at setup). See [Storage Format & Manual Editing](storage-format.md) for a manual workaround until you can capture the trigger.

## Home Assistant Integration Issues

### Device shows as unavailable in HA
- **API password**: Ensure the API password matches between ESPHome config and HA.
- **Network connectivity**: Verify the device is still connected to WiFi.
- **Restart HA**: Sometimes a Home Assistant restart resolves stale connections.

### Buttons/switches don't appear in HA
- **Reload integration**: Go to Settings > Devices & Services > ESPHome > Reload.
- **Check YAML**: Verify your ESPHome config has the correct entity definitions.

## Hardware Assembly Issues

### Smoke or burning smell during power-on
**IMMEDIATELY DISCONNECT POWER**
- Check for solder bridges between adjacent pads
- Verify component polarity (especially the AZ1117 regulator)
- Inspect for reversed components

### Components getting hot
- **AZ1117 regulator**: Mild warmth is normal; hot to touch indicates a short.
- **MOSFET**: Should stay cool during normal operation.
- **ESP-12F**: Moderate warmth during WiFi activity is normal.

## Getting More Help

If you're still stuck:

1. **Check existing issues**: [GitHub Issues](https://github.com/jaycollett/OpenIRBlaster/issues)
2. **Open a new issue**: Include your ESPHome logs and describe the problem in detail
3. **Community forums**: [Home Assistant Community](https://community.home-assistant.io/)

---

*Found a solution not listed here? PRs against this file are welcome.*

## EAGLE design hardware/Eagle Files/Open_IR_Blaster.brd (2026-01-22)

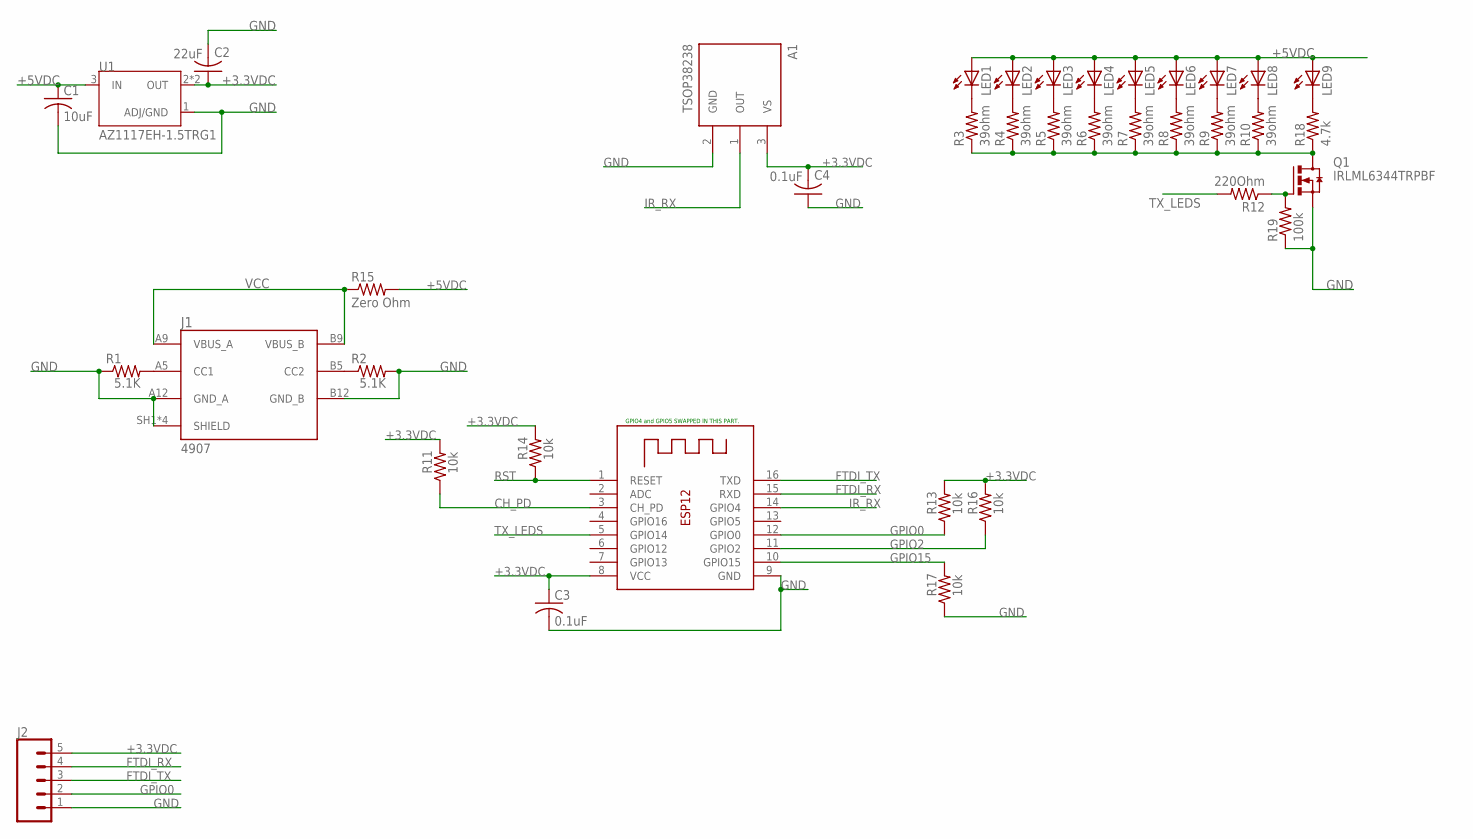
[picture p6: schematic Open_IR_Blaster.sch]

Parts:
A1: TSOP38238; XDCR_TSOP38238
C1: 10uF; C0805
C2: 22uF; C0805
C3, C4: 0.1uF; C0805
J1: 4907; ADAFRUIT_4907
J2: CONN_05PTH_LONGPADS; 1X05_LONGPADS
LED1, LED2, LED3, LED4, LED5, LED6, LED7, LED8: LED5MM
LED9: LEDCHIP-LED0603; CHIP-LED0603
Q1: IRLML6344TRPBF; SOT23
R1, R2: 5.1K; M0805
R3, R4, R5, R6, R7, R8, R9, R10: 39ohm; R1210
R11, R13, R14, R16, R17: 10k; M0805
R12: 220Ohm; M0805
R15: Zero Ohm; R1210
R18: 4.7k; R0603
R19: 100k; R0603
U1: AZ1117EH-1.5TRG1; SOT230P700X180-4N
X1: ESP-12

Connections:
+3.3VDC: A1.3 (VS), C2.1, C3.1, C4.2, J2.5, R11.2, R13.2, R14.2, R16.2, U1.2 (OUT), U1.4 (OUT), X1.8 (VCC)
+5VDC: C1.1, LED1.A, LED2.A, LED3.A, LED4.A, LED5.A, LED6.A, LED7.A, LED8.A, LED9.A, R15.2, U1.3 (IN)
CH_PD: R11.1, X1.3 (CH_PD)
FTDI_RX: J2.4, X1.15 (RXD)
FTDI_TX: J2.3, X1.16 (TXD)
GND: A1.2 (GND), C1.2, C2.2, C3.2, C4.1, J1.A12 (GND_A), J1.B12 (GND_B), J1.SH1 (SHIELD), J1.SH2 (SHIELD), J1.SH3 (SHIELD), J1.SH4 (SHIELD), J2.1, Q1.2 (S), R1.1, R2.2, R17.1, R19.1, U1.1 (ADJ/GND), X1.9 (GND)
GPIO0: J2.2, R13.1, X1.12 (GPIO0)
GPIO2: R16.1, X1.11 (GPIO2)
GPIO15: R17.2, X1.10 (GPIO15)
IR_RX: A1.1 (OUT), X1.14 (GPIO4)
unnamed: LED1.K (C), R3.2
unnamed: LED2.K (C), R4.2
unnamed: LED3.K (C), R5.2
unnamed: LED4.K (C), R6.2
unnamed: LED5.K (C), R7.2
unnamed: LED6.K (C), R8.2
unnamed: LED7.K (C), R9.2
unnamed: LED8.K (C), R10.2
unnamed: Q1.3 (D), R3.1, R4.1, R5.1, R6.1, R7.1, R8.1, R9.1, R10.1, R18.1
unnamed: J1.A5 (CC1), R1.2
unnamed: J1.B5 (CC2), R2.1
unnamed: Q1.1 (G), R12.1, R19.2
unnamed: LED9.C, R18.2
RST: R14.1, X1.1 (RESET)
TX_LEDS: R12.2, X1.5 (GPIO14)
VCC: J1.A9 (VBUS_A), J1.B9 (VBUS_B), R15.1

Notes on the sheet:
GPIO4 and GPIO5 SWAPPED IN THIS PART.

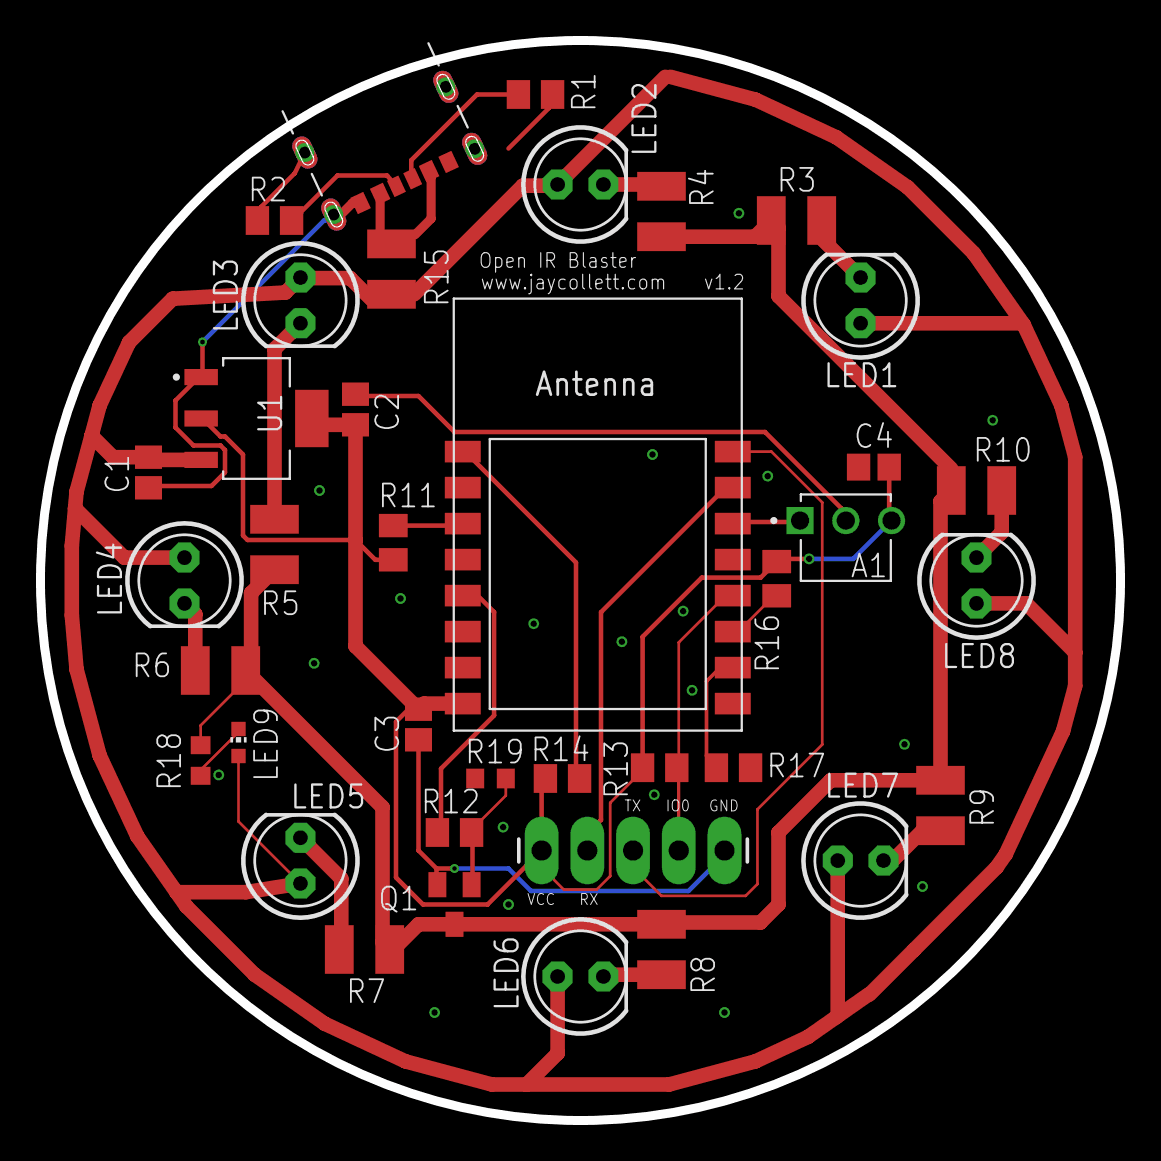
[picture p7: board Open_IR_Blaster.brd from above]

Board: 2 copper layers, 60.0 x 60.0 mm, 38 parts (0 on the bottom side), 26 nets.

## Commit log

2026-01-12 Initial commit: OpenIRBlaster Home Assistant Integration
    This integration provides comprehensive IR code learning, storage, and
    transmission capabilities for ESPHome-based IR blaster devices.
    Features:
    - Learn IR codes from any remote control
    - Store codes with names, tags, and notes
    - Button entities for easy code transmission
    - Multi-device support
    - Complete service API for automation
    - Real-time learning status sensors
    - Collision-safe storage with automatic ID generation
    Architecture:
    - Config Flow for easy setup
    - Options Flow for code management
    - Separate button and sensor platforms
    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
2026-01-13 Add integration assets and localization strings
    - Add assets/logo.png for branding
    - Add strings.json with localization for config flow, options, and services
2026-01-13 Add hardware design files and documentation
    - Add 3D printer files: Bottom.stl and Top.stl for enclosure
    - Add Eagle PCB design files: schematic and board layout
    - Add Bill of Materials (BOM.csv)
    - Add LICENSE file
    [BOM.csv, Bottom.stl, Open_IR_Blaster.brd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]
2026-01-13 Reorganize hardware files into hardware/ directory
    Move all hardware-related files into a single hardware/ directory:
    - 3DPrinterFiles/ (enclosure STL files)
    - Eagle Files/ (PCB design files)
    - BOM.csv (bill of materials)
    - factory_config.yaml (ESPHome firmware config)
    - factory_firmware.bin (precompiled firmware)
    [BOM.csv, Bottom.stl, Open_IR_Blaster.brd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]
2026-01-13 Fix critical firmware stability issues
    Config changes:
    - Change time platform from homeassistant to sntp (fixes Exception 28 crash on boot)
    - Enable API watchdog: reboot_timeout 0s -> 5min (auto-recovery from connection issues)
    - Use UTC timezone for SNTP (works without HA connection)
    Binary update:
    - Update factory_firmware.bin with latest build incorporating these fixes
    These changes prevent the null pointer crash during initial setup when device
    boots without Home Assistant connection (captive portal mode).
2026-01-13 Revert firmware configuration changes
    Revert back to original settings:
    - reboot_timeout: 0s (from 15min)
    - time platform: homeassistant (from sntp)
    Device works after automatic reboot, will address crashes in future update.
2026-01-13 Keep SNTP time platform configuration
    Restore SNTP time platform (revert_timeout stays at 0s).
    SNTP prevents issues when device boots without HA connection.
2026-01-13 Remove all comments from inside action blocks
    C++ preprocessor interprets any comment starting with # inside action blocks
    as preprocessing directives. Removed all such comments to fix compilation:
    - Removed comment before homeassistant.event action
    - Removed comment before debug lambda action
    - Removed comment before switch.turn_off action
    The actions are self-documenting and don't need inline comments.
2026-01-13 Restore comments that weren't causing compilation errors
    Only the comment before switch.turn_off was causing the C++ preprocessor error.
    Restored the other two comments:
    - Comment before homeassistant.event action
    - Comment before debug lambda action
2026-01-13 Add text-based IR code learning workflow
    Implements a user-friendly workflow for learning and managing IR codes:
    - Add text input entity for entering code names before learning
    - Auto-save learned codes with user-provided names (no more manual service calls)
    - Update sensors to persist last learned code info after save
    - Auto-delete codes from storage when button entities are removed
    - Fix config flow device discovery for devices with empty identifiers
    - Add persistent notifications for learning events
    - Add save_pending service for manual code saving
    - Update repository URLs from OpenIRBlasterIntegration to OpenIRBlaster
    The new workflow: type a code name, press Learn, point remote, done.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
2026-01-13 Add delete button for learned IR codes and fix sensor persistence
    - Add DeleteCodeButton entity for each learned code providing one-click deletion
    - Fix deletion workflow to use entity registry removal instead of integration reload
    - Persist sensor data (name, timestamp, pulse count) in hass.data across reloads
    - Update delete_code service to auto-detect config_entry_id when not provided
    - Initialize sensor persistence fields in __init__.py
    This improves UX by allowing users to delete codes with a simple button press
    instead of requiring Developer Tools or service calls. Sensors now retain their
    values after the integration reloads to create new button entities.
2026-01-13 Fix sensor data persistence across integration reloads
    - Add module-level cache (_SENSOR_DATA_CACHE) to preserve sensor data
    - Save sensor data to cache in async_unload_entry before unloading
    - Restore sensor data from cache in async_setup_entry after reload
    - Ensures Last Learned Name, Timestamp, and Pulse Count sensors retain
    their values when integration reloads to create new button entities
2026-01-13 Simplify and update README with current workflow
    - Rewrite in more user-friendly, less technical language
    - Update learning workflow to reflect text entity approach (not options flow)
    - Fix firmware path from hardware_config/ to hardware/firmware/
    - Add clear Quick Start Guide section with step-by-step instructions
    - Improve entity descriptions for better understanding
    - Add practical troubleshooting section with solutions
    - Include use case examples for inspiration
    - Remove overly technical architecture details (kept in CLAUDE.md)
    - Reorganize sections for better flow and readability
2026-01-13 Fix IR receiver GPIO pin and device_id handling
    Three critical fixes to enable IR code learning and transmission:
    1. Fix IR receiver GPIO pin (GPIO4 → GPIO5)
    - Hardware schematic shows GPIO4/GPIO5 are swapped in ESP-12F footprint
    - TSOP38238 IR receiver OUT pin connects to GPIO5, not GPIO4
    - Updated factory_config.yaml and CLAUDE.md documentation
    2. Fix device_id to include MAC suffix
    - Home Assistant adopts ESPHome devices with MAC suffix (e.g., openirblaster-64c999)
    - Firmware was sending device_id without suffix, causing event filtering mismatch
    - Added MAC suffix construction in both event handler and debug sensor
    - Device_id now dynamically constructed as "openi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
2026-01-14 Implement two-device architecture and improve learning workflow
    Changes:
    - Split into main device (IR code buttons) and controls device (learning/management UI)
    - Add duplicate code name detection with user notification
    - Disable delete buttons by default for safety
    - Clear pending code on duplicate name to prevent double notifications
    - Move Learn, Send Last, Delete buttons and Code Name text input to controls device
2026-01-19 Update firmware to v0.2.0: use name_add_mac_suffix for unique device IDs
    - Enable name_add_mac_suffix: true so ESPHome auto-appends MAC suffix
    - Simplify device_id to use App.get_name() directly (no manual MAC construction)
    - This ensures unique device names across multiple OpenIRBlaster devices
2026-01-19 Add factory_flash.yaml for initial device flashing
    Two-file firmware architecture:
    - factory_flash.yaml: For factory flashing, uses name_add_mac_suffix: true
    so devices advertise with unique names (e.g., openirblaster-64c999)
    - factory_config.yaml: Pulled from GitHub on ESPHome adoption, uses
    name_add_mac_suffix: false since ESPHome captures the full unique name
    This prevents the double MAC suffix issue when devices are adopted.
2026-01-19 Simplify to single firmware - remove ESPHome dashboard dependency
    - Remove factory_config.yaml (no longer needed)
    - Remove dashboard_import from firmware
    - Bump version to 0.3.0
    New simplified flow:
    1. Factory flash device with factory_flash.yaml
    2. User connects to WiFi via captive portal
    3. HA auto-discovers device via ESPHome integration
    4. User adds OpenIRBlaster integration
    No ESPHome dashboard adoption required - firmware is complete.
2026-01-20 Add factory_flash.bin for easy device flashing
    Pre-compiled firmware binary for users to flash devices without
    needing to compile from source.
2026-01-20 Prepare integration for HACS publishing
    Major changes:
    - Add HACS configuration (hacs.json)
    - Fix device discovery fallback for empty ESPHome identifiers
    - Add helpers.py for ESPHome service discovery
    - Improve config flow robustness for multi-device support
    - Update README with new firmware installation instructions
    - Add minimum HA version requirement to manifest
    Code quality improvements:
    - Fix timezone-naive datetime in storage.py
    - Services now raise exceptions instead of silent returns
    - Extract magic strings to constants
    - Fix service field naming consistency in strings.json
    - Remove unused imports and fix deprecated Callable import
    Device identification:
    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
2026-01-20 Restore last learned sensors across restarts
2026-01-20 Add options-flow delete for codes
2026-01-20 Fix options flow init
2026-01-20 Fix options flow config entry init
2026-01-20 Harden options flow config entry handling
2026-01-20 Remove entities when deleting via options flow
2026-01-20 Show device name in code delete list
2026-01-20 Tighten delete cleanup and simplify dropdown
2026-01-20 Remove per-code delete button entities
2026-01-20 Remove storage migration and sensor cache
2026-01-22 Adds indicator LED to board and pulldown for MOSFET (not required).
    [Open_IR_Blaster.brd, Open_IR_Blaster.sch]
2026-01-27 Update README with HACS installation instructions and accuracy fixes
    - Add complete step-by-step HACS installation instructions (now in default store)
    - Clarify that ESPHome devices must be set up before adding integration
    - Fix inaccurate "automatic discovery" language in Quick Start
    - Add troubleshooting note about ESPHome device adoption requirement
2026-01-31 Add schematic PNG to hardware files
2026-02-04 Add MAC address to learned events for stable device identification
    - Include MAC address in esphome.openirblaster_learned event payload
    - Enables HA integration to identify devices by hardware MAC instead of
    ESPHome device name, preventing duplicate devices when YAML changes
    - Re-add dashboard_import for ESPHome Builder adoption
    - Bump firmware version to 0.4.0
2026-02-04 v1.0.2: MAC-based device identification to prevent duplicates
    Closes #1
    This release fixes the duplicate device issue that occurred when users
    modified their ESPHome YAML configuration.
    - Use MAC address as primary device identifier instead of ESPHome device name
    - Capture MAC address during config flow setup
    - Filter learned events by MAC address first, fall back to device_id
    - Add async_remove_entry for proper cleanup on integration removal
    - Consistent MAC-based identifiers across all entity files
    - Update firmware to v0.4.0 with mac_address in learned events
    The MAC address is hardware-bound and never changes, ensuring stable
    device identification even after firmware updates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
2026-02-05 Remove current release version from README
    Removed current release version from README.
2026-02-05 Add CI/CD workflows and branch protection
    - Add ci.yml: runs pytest, ruff linting, and version check on PRs
    - Add release.yml: auto-creates GitHub releases when PRs merge to master
    - Fix validate.yaml: scope triggers to master branch only (prevents doubled checks)
    - Add mock esphome integration for tests (satisfies dependency requirement)
    - Fix test_config_flow.py: update tests for discovery-based config flow
    - Fix test_learning.py: fix async clear_pending test, add persistent_notification mock
    - Fix learning.py: strict MAC matching when both session and event have MAC addresses
    - Add CONF_ESPHOME_SERVICE_NAME to test fixtures
    - Bump version to 1.0.4
    - Branch protection configured on master: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
2026-04-23 Add third-party device support docs
    Introduces docs/third-party-devices/ as a home for community guides
    covering hardware that wasn't designed for OpenIRBlaster. Seeds the
    section with a Tuya IR blaster guide (pinouts for S06/S18 across CBU,
    CB3S, C3BS, W3BS boards plus an ESPHome YAML template) contributed via
    issue #5, and links the new section from the README.
2026-04-23 Bump version to 1.0.5
    - Default Code Name field to blank instead of placeholder text (#6)
    - Add third-party device support docs section, seeded with Tuya IR
    blaster guide contributed via #5
2026-04-23 Clean up CI: remove dead test mock, bump GitHub Actions to Node 24
    - Delete unused tests/components/esphome mock package. The current
    conftest.py mocks ESPHome via loader.async_get_integration patching
    rather than a custom_components-style fixture, so this directory was
    dead code. Hassfest was scanning it as if we were Home Assistant
    core, which produced two spurious warnings on every Validate run:
    'Domain collides with built-in core integration' (collided with the
    real esphome core integration) and a CONFIG_SCHEMA warning on its
    unused async_setup stub.
    - Bump actions/checkout v4 -> v6, actions/setup-python v5 -> v6,
    softprops/action-gh-release v2 -> v3, and actions/stale v9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
2026-04-24 Add text_sensor fallback path for learning capture
    Learning sessions now watch the ESPHome payload text_sensor in addition
    to the learned event. If the ESPHome API socket drops the event (which
    happens under transient CONNECTION_CLOSED errors), the text_sensor state
    replays on reconnect and we capture the code via that path instead.
    Both paths share a single validator/committer (_process_capture_payload)
    and a _capture_finalized guard so the code is only accepted once, no
    matter which path arrives first.
2026-04-24 Add tests for text platform, fallback capture, and callback lifetime
    Covers:
    - tests/test_text.py: native_value defaults to empty string, set_value
    writes through, min/max constraints, controls-device assignment (both
    MAC-based and device_id-based), unique_id namespacing.
    - tests/test_learning.py: text_sensor fallback captures identically to
    the event path; dedup guard holds when event arrives first, when
    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
2026-04-24 Back-fill MAC address from ESPHome device registry on setup
    Older config entries predate MAC capture in the config flow. Without a
    MAC the text_sensor fallback resolver is limited to its slug-based
    Strategy 2, which is fragile when a user has customized the ESPHome
    entity naming. Strategy 1 (device-registry lookup by MAC) is the
    robust path, but it requires the MAC to be present in entry.data.
    On setup, if CONF_MAC_ADDRESS is absent we scan the HA device registry
    for an ESPHome-owned device matching the configured device_id (by
    name, friendly name, or identifier substring), extract its MAC
    connection, and update the config entry data in place. Users with
    legacy installs gain the robust reso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
2026-04-24 Expand learning test coverage for resolver, race guard, and MAC back-fill
    Adds tests that QA flagged as missing or weak in the issue #8 review:
    - Strategy 1 resolver: verify device-registry-by-MAC lookup succeeds
    even when the Strategy 2 slug heuristic would miss (custom ESPHome
    entity naming). Proves Strategy 1 works independently of Strategy 2.
    - Resolver returns None: confirm graceful degradation - event path
    stays subscribed, state_listener is None, warning is logged.
    - Validation-failure race: assert _capture_finalized flips synchronously
    on a bad text_sensor payload and blocks a subsequent valid event from
    committing, closing the S1/S2 race window.
    - MAC back-fill (happy pat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
2026-04-24 Tighten ESPHome MAC back-fill matcher to avoid ambiguous picks
    Previously the back-fill scanned the device registry with a pure
    substring match and returned the first matching device, which could
    silently assign the wrong MAC when a user has multiple ESPHome devices
    with overlapping node names (e.g. 'openirblaster-293aea' and
    'openirblaster-293aea-spare').
    The tightened matcher prefers exact matches on device name,
    name_by_user, or identifier value. Substring matches are only used as a
    fallback, and only when exactly one substring candidate carries a MAC
    connection; if multiple candidates tie, we log a warning and refuse to
    guess. Returning None in the ambiguous case is safe: the caller
    gra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
2026-04-24 Bump version to 1.0.6
    Fixes IR learning that broke after HA 2026.4 + ESPHome 2026.4 when
    transient native-API socket disconnects caused the `esphome.openirblaster_learned`
    event to be lost. The integration now subscribes to the firmware's
    `last_ir_raw_snippet` text_sensor as a secondary capture path, which
    survives reconnects, and dedups against the event path.
    Also fixes a callback-registration leak in the Learn button that could
    produce duplicate save attempts after repeated timeouts, and back-fills
    the ESPHome device MAC on setup for older config entries so the
    fallback's stable device-registry resolver is available without
    reconfiguration.
    Closes #8.
2026-05-20 Fix dangling-pointer MAC and rebuild dropped-event recovery (v1.0.7 / firmware 0.5.0)
    Two bundled fixes for issue #11 and a long-standing latent failure in the
    text_sensor fallback path:
    1. Firmware MAC field was a dangling pointer.
    The on_raw lambda returned WiFi.macAddress().c_str(), which is a pointer
    into an Arduino String temporary. The String dies at the end of the
    lambda's return statement, so by the time ESPHome's templating wrapper
    copies the value into a std::string for the protobuf field the buffer
    has been freed and reused. HA receives garbage in the mac_address field
    and the protobuf parser rejects the whole message as bad UTF-8, killing
    the API socket. Fi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
2026-06-12 Modernize HA integration, fix learning races, add repairs and reconfigure flow (v1.1.0)
    Stability fixes:
    - Make learning-start atomic so concurrent starts cannot leak event listeners
    - Close capture-vs-timeout race that could emit a spurious TIMEOUT after a capture
    - Track all background tasks via hass.async_create_task / async_call_later
    - Clean up entity registry when codes are deleted via the delete_code service
    - Clean up session and entry data when platform setup fails
    - Guard options-flow save against a pending code cleared mid-form
    - Make learn_start timeout per-session instead of mutating the default
    - Enforce duplicate-name checks on all save paths
    Home Assistant alignment (Bronze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
2026-06-12 Replace entry reloads with dynamic entities, add event platform and learn_cancel, fix QA findings
    - Code add/delete/rename now updates entities live via dispatcher signals
    instead of reloading the config entry; learning sessions survive saves
    - Management entities use entity categories on the main device; the virtual
    "Controls" device is removed with an idempotent registry migration that
    preserves user customizations (covers both MAC and device_id identifiers)
    - New event entity (code_learned / code_saved) for automations
    - learn_start, send_code, and save_pending support optional response data
    - New learn_cancel service; learn_start can restart from terminal states
    Fixe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
2026-06-12 Disable polling on push-based entities and bump version to 1.2.0
    The event, sensor, and text entities are purely push-driven but inherited
    the default should_poll=True, so their platforms scheduled a needless
    polling interval timer (flagged as a lingering timer by the CI test
    harness). Button entities were already non-polling via the core base.
2026-06-12 Sweep orphaned entity registry entries at setup (v1.2.1)
    Old integration versions left stale entity registry entries behind,
    most notably the per-code delete buttons removed in January without
    registry cleanup. Setup now removes any registry entry owned by the
    integration whose unique_id is not in the authoritative set (static
    entities plus one button per stored code), logging each removal. The
    sweep is idempotent, scoped to the config entry and platform, and
    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
2026-06-12 Document v1.2.x add/rename/delete workflows and entity layout (v1.2.2)
    Rewrite docs/home-assistant-integration.md for the current flow: single
    device layout with entity categories, the Code Activity event entity,
    learning via UI and services (including responses and learn_cancel),
    the two-step delete flow, reconfigure, Repairs reference, and startup
    housekeeping. Fix service examples that used a nonexistent code_id
    field.
2026-06-12 Add code management steps to README quick start (v1.2.3)
    Cover rename and the two-step delete flow in the quick start and point
    to the full integration docs for the service reference.
2026-09-20 Pin ruff and fix hassfest validation (v1.3.1)
    Master went red on CI and Validate after v1.3.0. Two independent causes,
    neither of which needed a code change to trigger.
    The linter was unpinned. requirements_dev.txt asked for ruff>=0.1.0, so
    CI installed whatever was newest, and ruff 0.16 expanded its default rule
    set. Twenty-eight findings appeared in code that had not changed, most of
    it older than this release. Reproduced by installing 0.16.8 into a clean
    environment and running the exact CI command: 28 errors there, 0 under
    the 0.15.12 the local environment happened to have.
    ruff is now pinned to 0.16.8 and the local environment matches, so the
    two cannot drift apart again on someone el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
2026-09-30 Trim CLAUDE.md to standing rules
    Drop the module map and data flow derivable from the code; keep commands, constraints, and the learning state machine.

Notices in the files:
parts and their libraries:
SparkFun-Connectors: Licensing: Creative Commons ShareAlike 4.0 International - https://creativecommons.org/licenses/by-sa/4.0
